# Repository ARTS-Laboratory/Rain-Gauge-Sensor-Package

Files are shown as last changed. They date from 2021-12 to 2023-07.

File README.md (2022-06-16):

# Rain-Gauge-Sensor-Package
Measuring the rain

<p align="center">
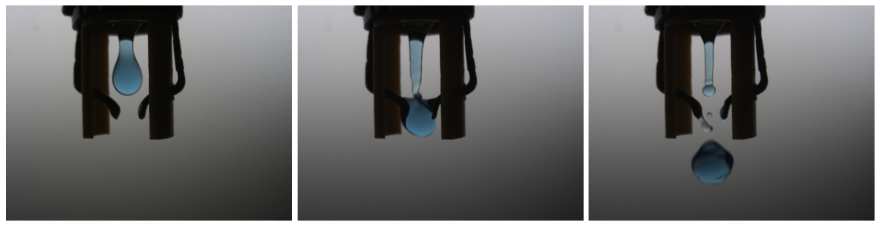
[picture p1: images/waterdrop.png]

</p>
<p align="center">
Figure 1: Water drops through the contacters.
</p>

<p align="center">
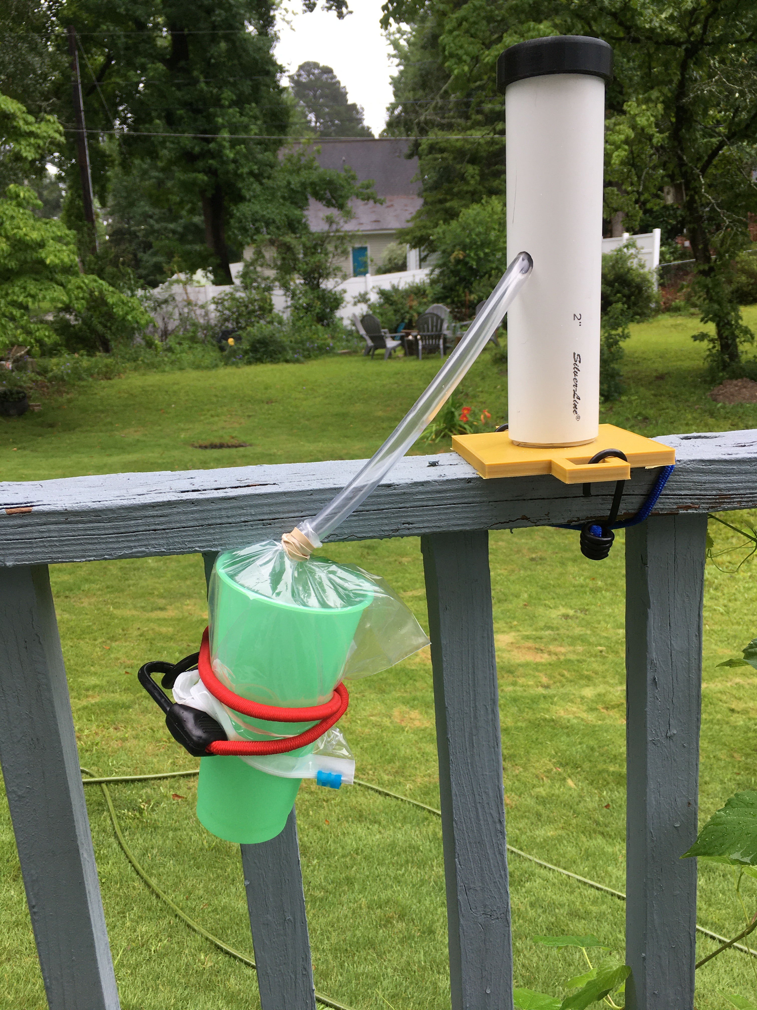
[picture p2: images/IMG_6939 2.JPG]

</p>
<p align="center">
Figure 2: Testing water drop measurments in (Saif 2021).
</p>

<p align="center">
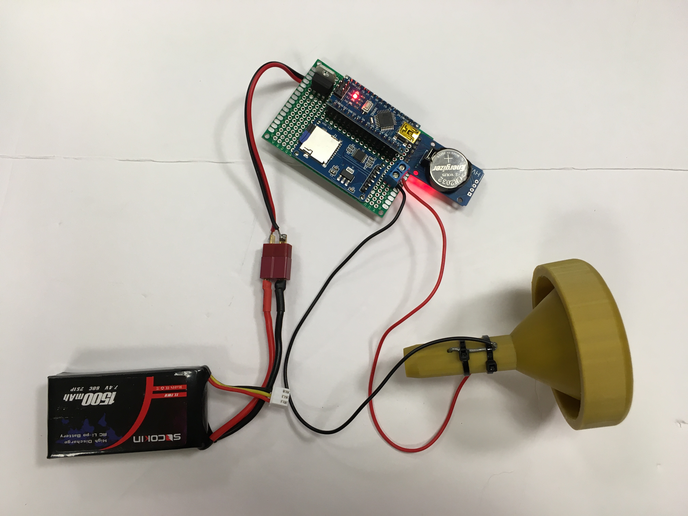
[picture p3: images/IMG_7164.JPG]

</p>
<p align="center">
Figure 3: Prototype hardware.
</p>

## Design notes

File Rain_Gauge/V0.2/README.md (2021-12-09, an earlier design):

# magDrone/Hydrologic Parameters/V0 Development/V 0.6/Raingauge
This is the drop counter verson of the raingauge for all previous versions see v0.5 folder (piezoelectric, resistivity, capacitance, and pressure)

##  How it works
- See powerpoint
- Raindrops are funneled together
- Individual drops are reformed using a Nozzle
- Individual drops fall from nozzle and are detected by electroids
- Drops continue into collection area and drain from the system

## As of 5/6/2021
- Drop formation size of 0.007675 in^3/drop
- Intake area of 4.43014 in^2
- Resolution of 0.001732 inches of water (per drop)

### What we have
- CAD files
  - Funnel
  - Nozzle/electrodes/drainage system
- Lab testing
- Data results

###  Next Steps
- integrate with PCB package
- Outdoor testing
- Get more data
- Find optimum nozzle parameters
- Determine drop parameters for nozzle
- CFD of drop formation

##### NOTE: Project being passed of from Richard Keith Matthews as of 5/6/2021. Email: Keithmatthews440@gmail.com

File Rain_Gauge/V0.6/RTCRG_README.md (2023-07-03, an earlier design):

## Update v0.6.2- June 2,2023
Current version is capable of turning on or off based on environmental humidity readings and an RTC interrupt. The RTC also logs the time it detects rainfall.

# Purpose of this project is to create an electronic rain gauge that can be deployed long term. It measures rainfall by counting individual rain drops as they make contact with two electrodes. The overall design is that of a funnel that guides rain through the electrodes so they can be counted individually, and saves this data, along with the time and humidity, to a microSD card.

BOM: Arduino Nano, BME280, 3.3v microSD card adapter, RTC module, 10uF capacitor, 3M ohm resistor, 5V and 3.3V linear regulators, 7.4V lipo battery

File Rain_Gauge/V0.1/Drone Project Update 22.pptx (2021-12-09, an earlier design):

## Rainfall sensor Update

Keith Matthews

## Rainfall sensor

- No moving parts
- High accuracy: drop counting
- Counts individual drops per area
- Converted to inches/hour
- Water drains out the bottom

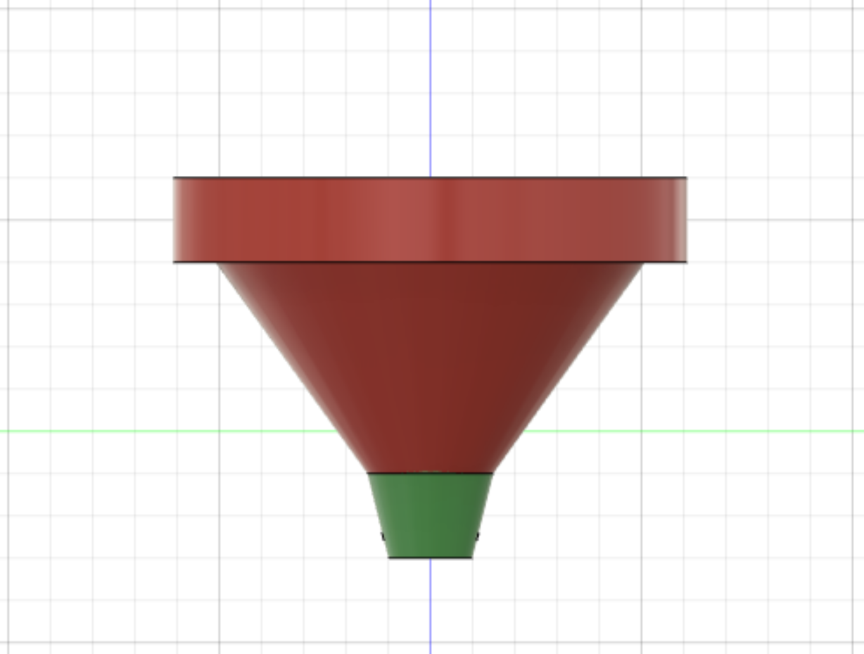
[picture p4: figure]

Funnel

Internal Nozzle

Electrodes

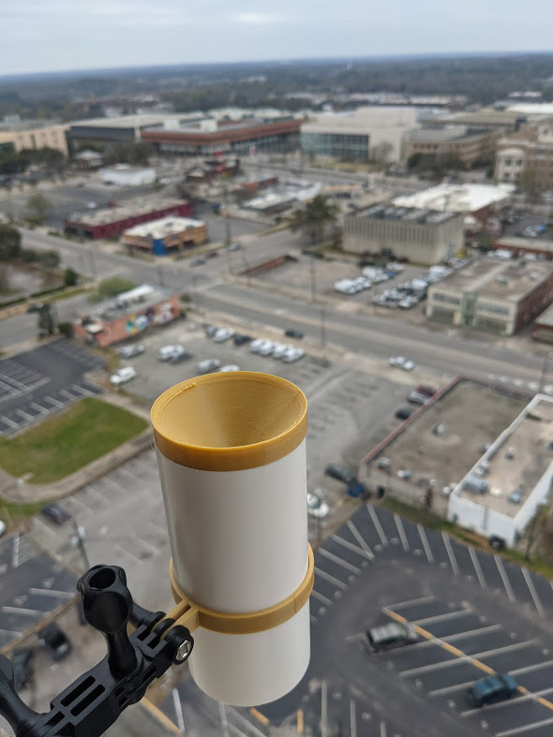
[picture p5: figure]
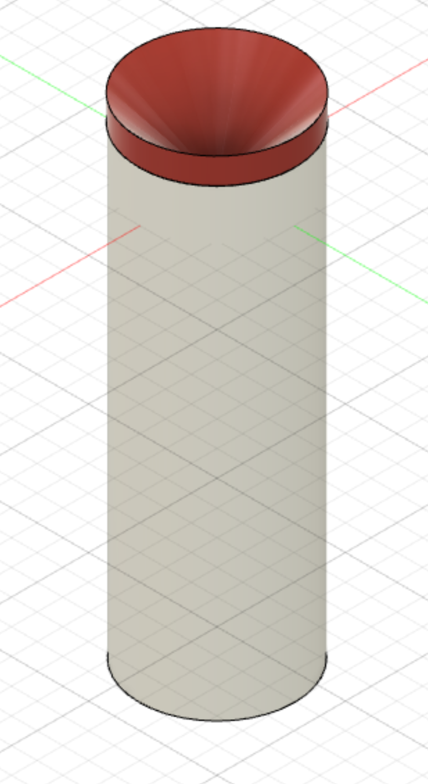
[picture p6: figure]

## Thoughts, Question, or Advise?

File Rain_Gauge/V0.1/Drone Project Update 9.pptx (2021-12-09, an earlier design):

## Water probe and Rainfall sensor Update

Keith Matthews

## Measuring Nitrates

- Chemical Test: Ring Test (iron(II) sulfate and sulfuric acid)
- In Situ with UV absorption?
  - Servo: to move the diffuser
  - Monochromator
  - Source (Sun?)
  - Detector (photosensor)
- Measurement range
- Detect other materials in the water?

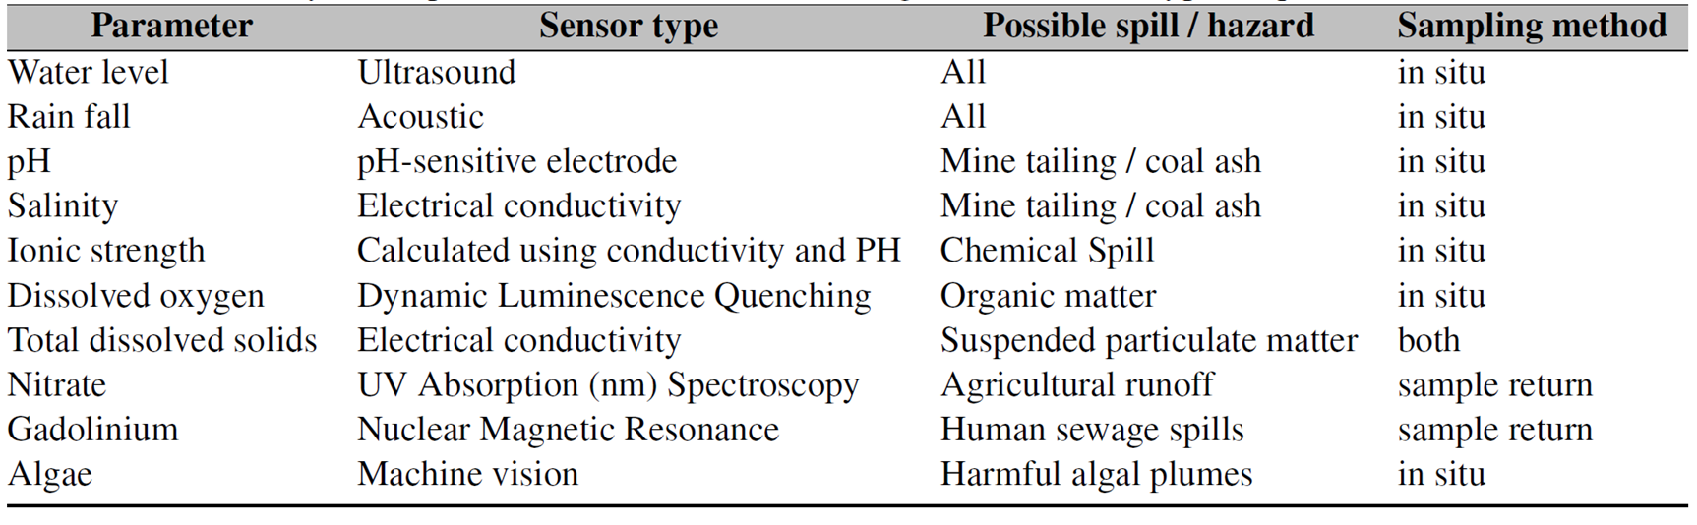
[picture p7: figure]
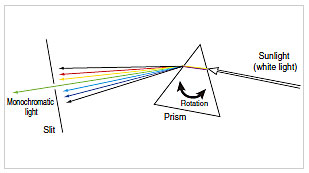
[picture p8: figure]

Monochromator

Angle determines the wavelength

## Nitrates

- Determination of Nitrate in Water Containing Dissolved Organic Carbon by Ultraviolet Spectroscopy
- 200-205 nm & 300 nm
- 2 wavelengths avoid organic intereference

## Dissolved oxygen

- Rapid and precise determination of dissolved oxygen by spectrophotometry: Evaluation of interference from color and turbidity
- 430nm
- Low organic interference

## Uv absorption

- Sample return
  - Easiest
- Fixed wavelengths
  - Nitrates only
- Spectrum
  - Moving parts
  - ∆θ=∆λ= accuracy
  - Slit size = precision

## Battery

- Samsung cylinder batteries?
  - Stackable
  - Flexible design
  - One charger for all
- LiPo
- Charging?
- Replacing

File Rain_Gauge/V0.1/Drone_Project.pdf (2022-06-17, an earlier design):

# WATER PROBE AND RAINFALL SENSOR UPDATE

Keith Matthews

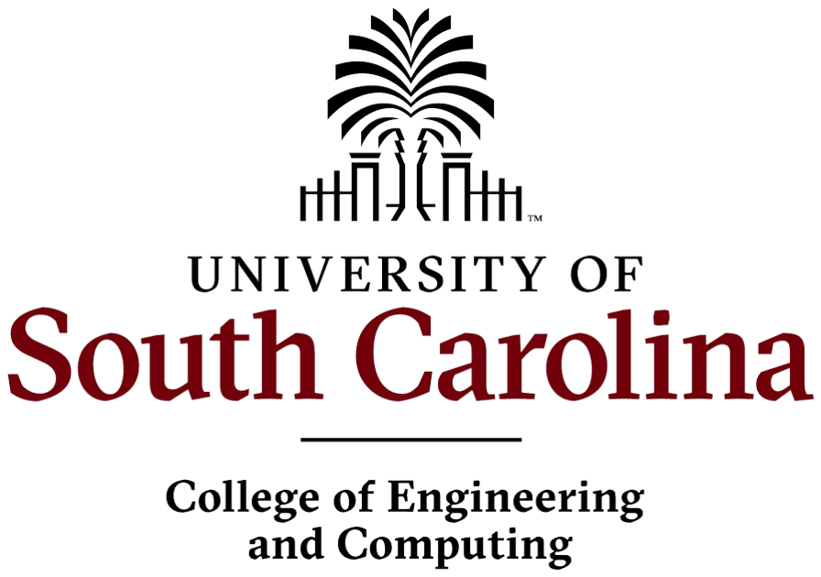
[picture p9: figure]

## RAINFALL SENSOR

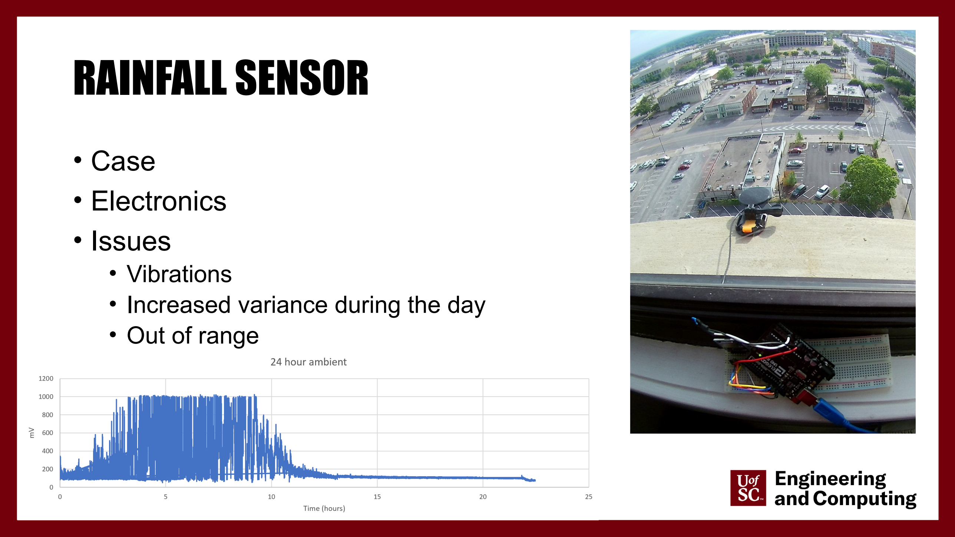
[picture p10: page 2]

- Case
- Electronics
- Issues
- Vibrations
- Increased variance during the day
- Out of range

## PIEZOELECTRIC RAINFALL SENSOR

- Conversion Factor
- Piezo: measurement mV
- Deflection- caused by Force
- Need “Velocity” – inches per hour
- Mathematical(ish)
- Voltage = Energy per electrical charge ~ Energy (constant amperes)
- Voltage ~ K.E. = (assume terminal velocity)
- Velocity
- Statistically
- Linear Regression:

## AUTO RIGHTING

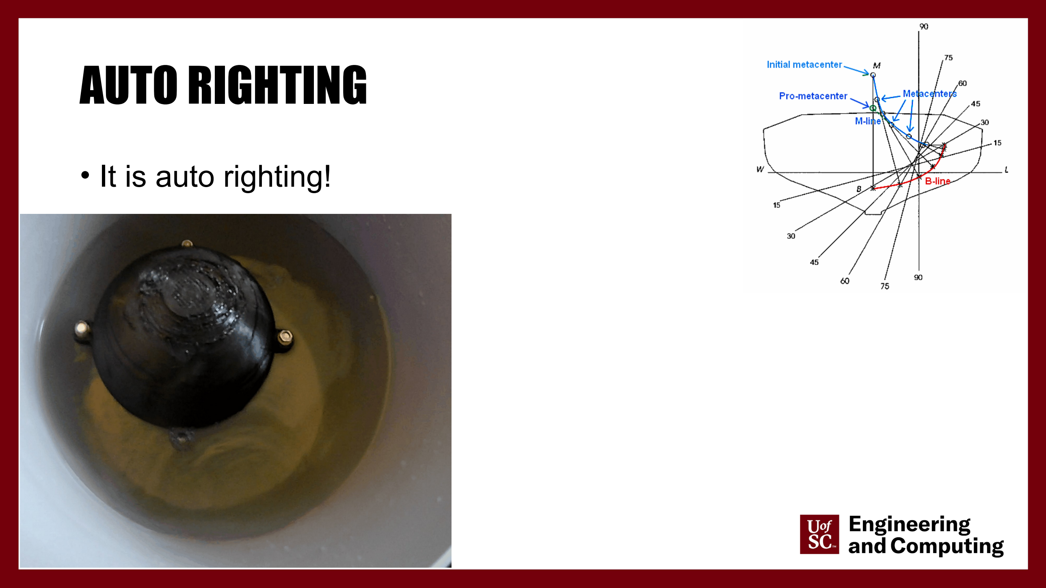
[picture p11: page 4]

- It is auto righting!

## WATERPROOF

- Mostly: only one leak
- Small imperfection in base print causing leak
- Higher quality prints take days
- Still not guaranteed
- Waterproof Electronics box

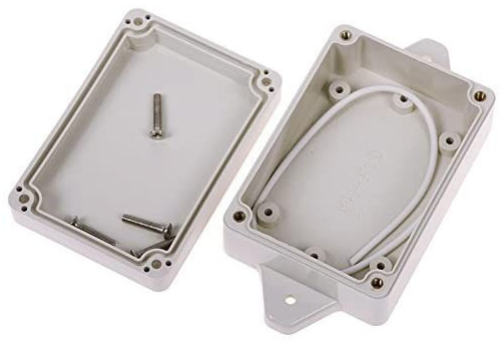
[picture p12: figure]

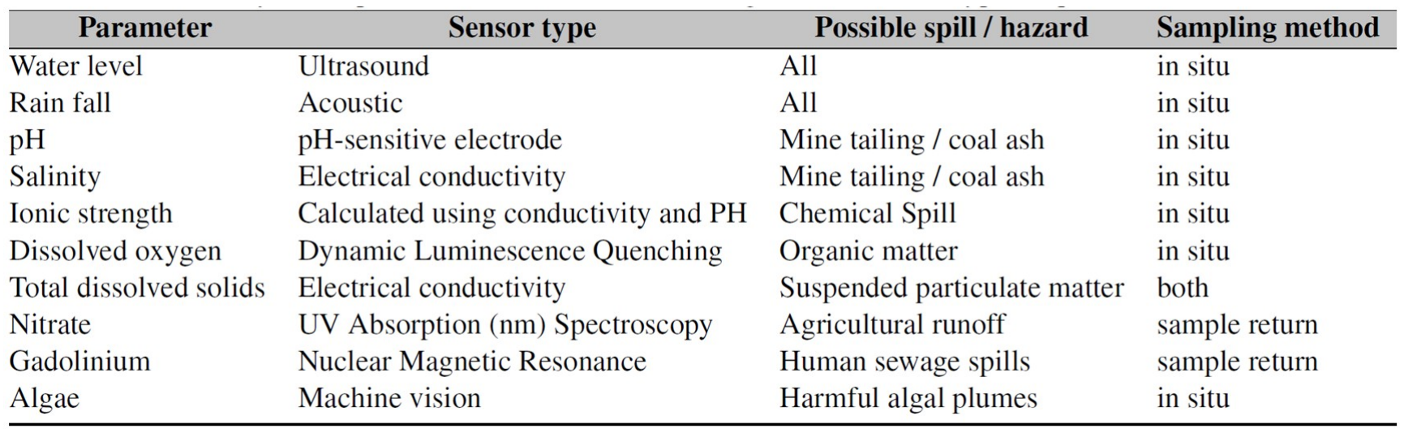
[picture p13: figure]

## MEASURING NITRATES

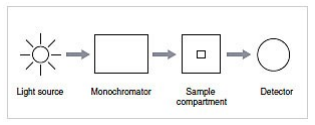
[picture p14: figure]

- Chemical Test: Ring Test (iron(II) sulfate and sulfuric acid)
- In Situ with UV absorption?
- Servo: to move the diffuser
- Monochromator
- Source (Sun?)
- Detector (photosensor)
- Measurement range
- Detect other materials in the water?

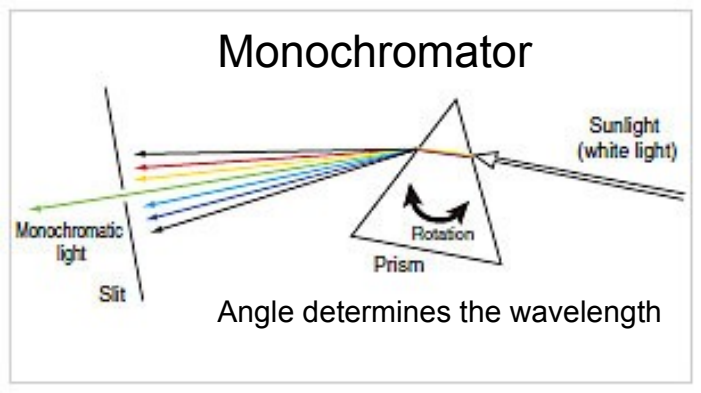
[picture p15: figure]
Angle determines the wavelength; Monochromator

## NEXT STEPS

- Rainfall
- Case V1
- Regression Equation
- Mounting System
- Water Probe
- Case V3
- Field testing
- Test Sensor System

## SOURCES

- https://pubs.rsc.org/en/content/articlelanding/2018/en/c8en0058 8e#!divAbstract (https://pubs.rsc.org/en/content/articlelanding/2018/en/c8en00588e#!divAbstract)
- http://www.pitt.edu/~asher/homepage/spec_pdf/UV%20Resona nce%20Raman%20Spectroscopic%20Detection%20of%20Nitra te.pdf (http://www.pitt.edu/~asher/homepage/spec_pdf/UV%20Resonance%20Raman%20Spectroscopic%20Detection%20of%20Nitrate.pdf)
- https://www.shimadzu.com/an/uv/support/fundamentals/monoch romators.html (https://www.shimadzu.com/an/uv/support/fundamentals/monochromators.html)

## DISSOLVED OXYGEN

## BATTERY

- Samsung cylinder batteries?
- Stackable
- Flexible design
- One charger for all
- LiPo
- Charging?
- Replacing

## TABLE OF PARAMETERS

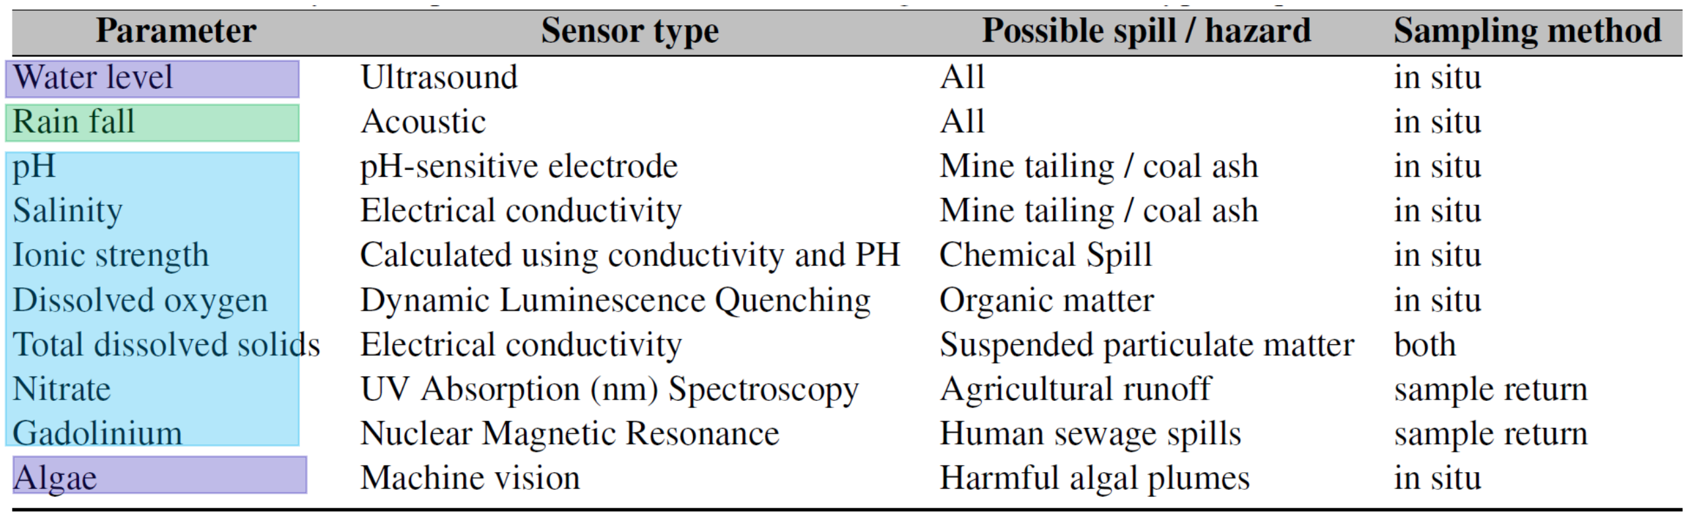
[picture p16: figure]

## PACKAGE CONDITIONS

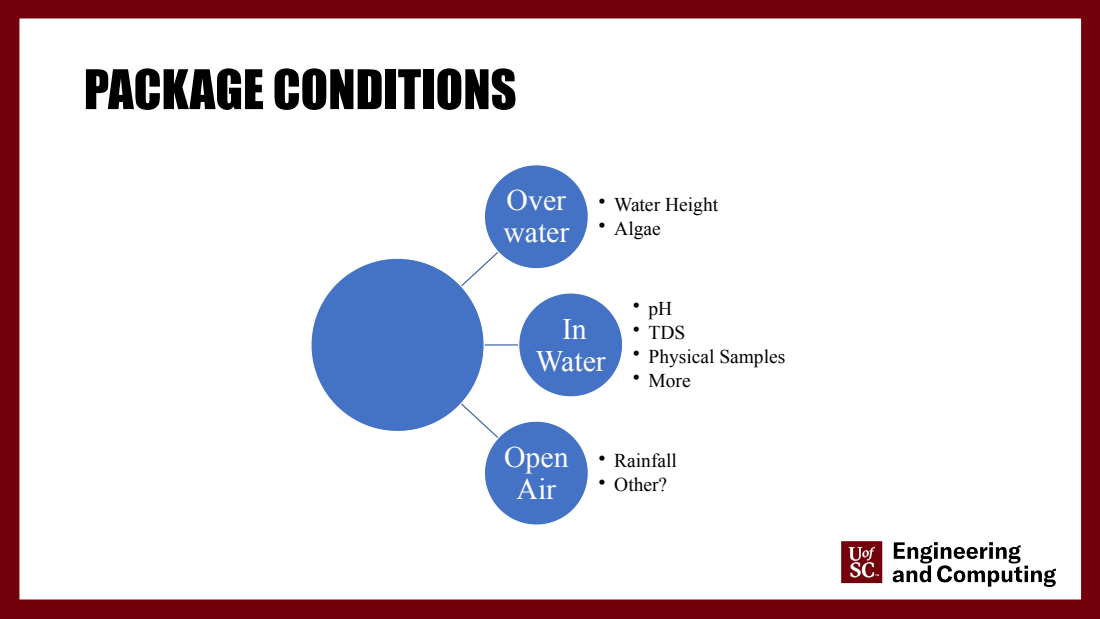
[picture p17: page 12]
Over water; • Water Height • Algae; In Water; • pH • TDS • Physical Samples • More; Open Air; • Rainfall • Other?

## 3 PACKAGES

- Above water package
- Currently the water height sensor package
- Add camera for algae machine vision detection capabilities
- In water package
- Under development
- Open air package
- Testing/development

## PROBE SWAP

- Easier
- Eliminates Docking

## MEASURING NITRATES

- Chemical Test: Ring Test (iron(II) sulfate and sulfuric acid)
- In Situ with UV absorption?
- Servo: to move the diffuser
- Monochromator
- Source (Sun?)
- Detector (photosensor)
- Measurement range
- Detect other materials in the water?

## NITRATES

- Determination of Nitrate in Water Containing Dissolved Organic Carbon by Ultraviolet Spectroscopy
- 200-205 nm & 300 nm
- 2 wavelengths avoid organic intereference

## DISSOLVED OXYGEN

- Rapid and precise
determination of dissolved oxygen by
spectrophotometry:
Evaluation of interference from color and turbidity
- 430nm
- Low organic interference

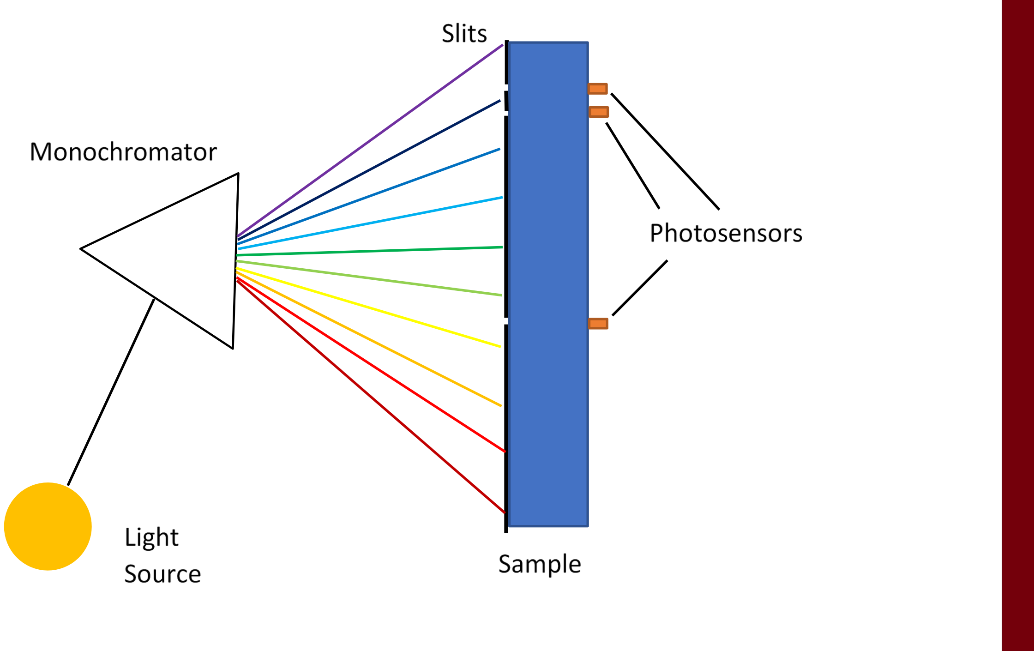
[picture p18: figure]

## UV ABSORPTION

- Sample return
- Easiest
- Fixed wavelengths
- Nitrates only
- Spectrum
- Moving parts
- accuracy
- Slit size precision

## BATTERY

- Samsung cylinder batteries?
- Stackable
- Flexible design
- One charger for all
- LiPo
- Charging?
- Replacing

## DATA

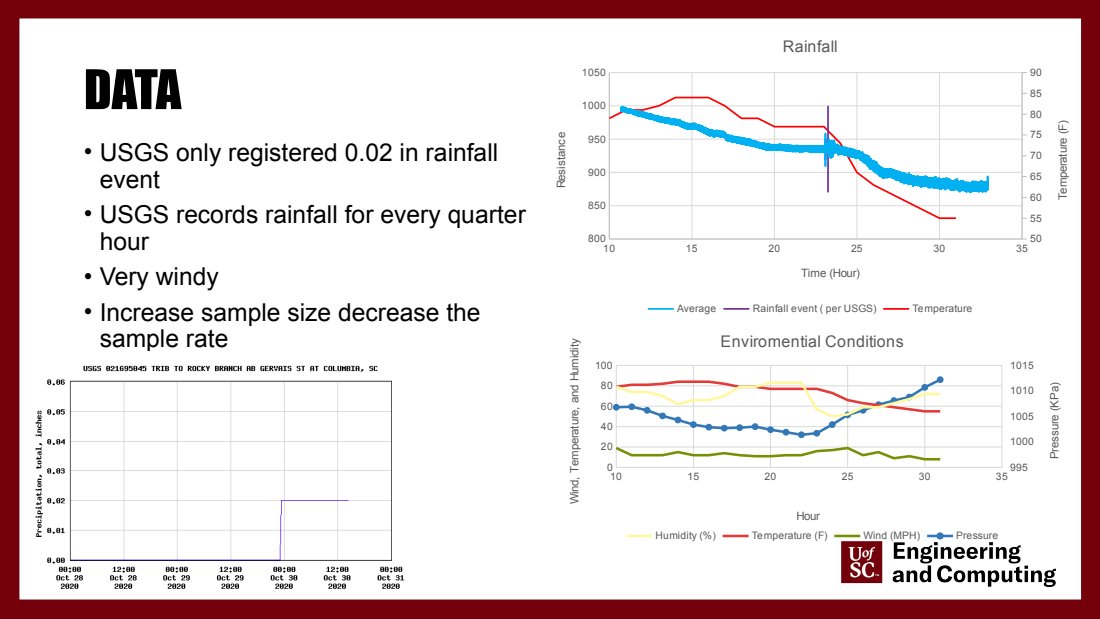
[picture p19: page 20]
Rainfall; Average; Rainfall event ( per USGS); Temperature; Time (Hour); Resistanc; erature (F); Enviromential Conditions; Humidity (%); Temperature (F); Wind (MPH); Pressure; Hour; Wind, T; erature, and; Humidity; Pressure (K

• USGS only registered 0.02 in rainfall
event
• USGS records rainfall for every quarter
hour
• Very windy
• Increase sample size decrease the
sample rate

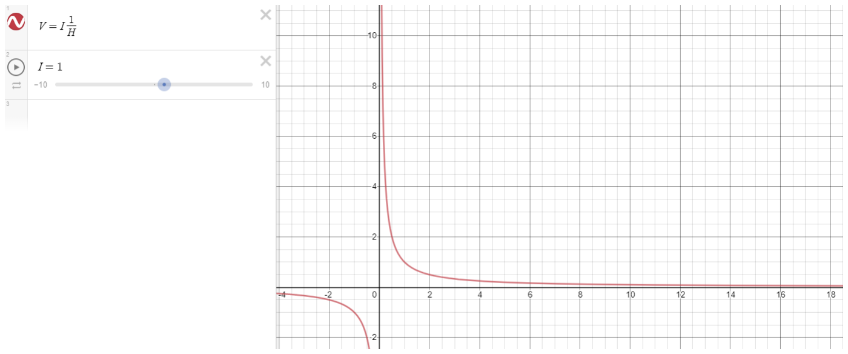
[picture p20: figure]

## REDESIGN TOP PIECE

- Deformation internal electrode holder
- Due to heat
- Make thicker and connect
- Reciprocal Function
- V=IR = I*(1/H)
- Flatten the curve
- Increase the current
- Angle the electrodes?
0 | 2 | 4 | 6 | 8 | 10 | 12

0

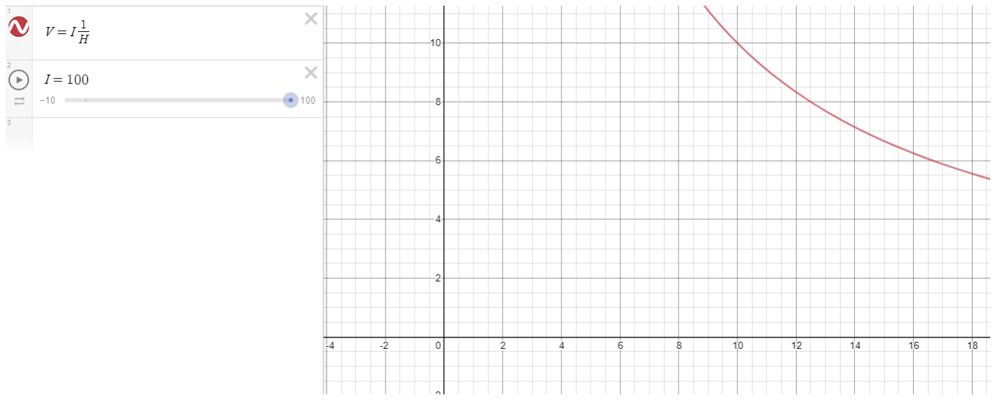
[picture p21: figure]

2

4

6

8

10

12

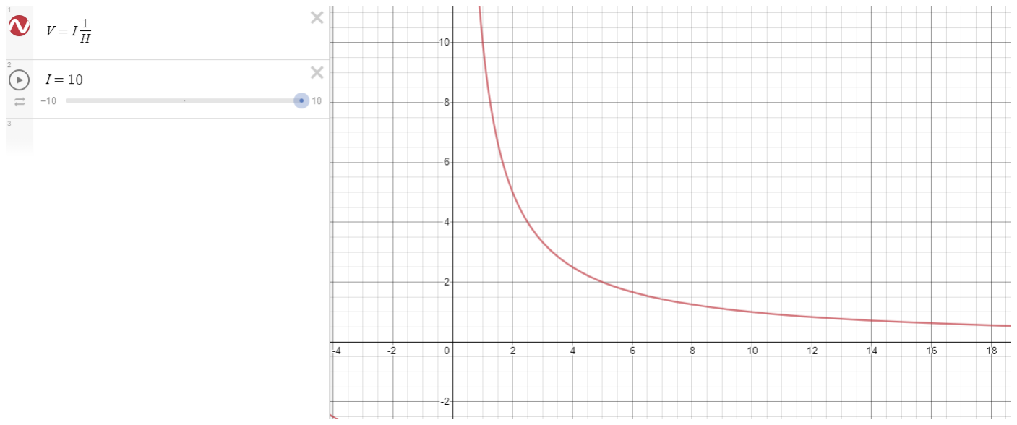
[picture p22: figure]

## NEW TOP

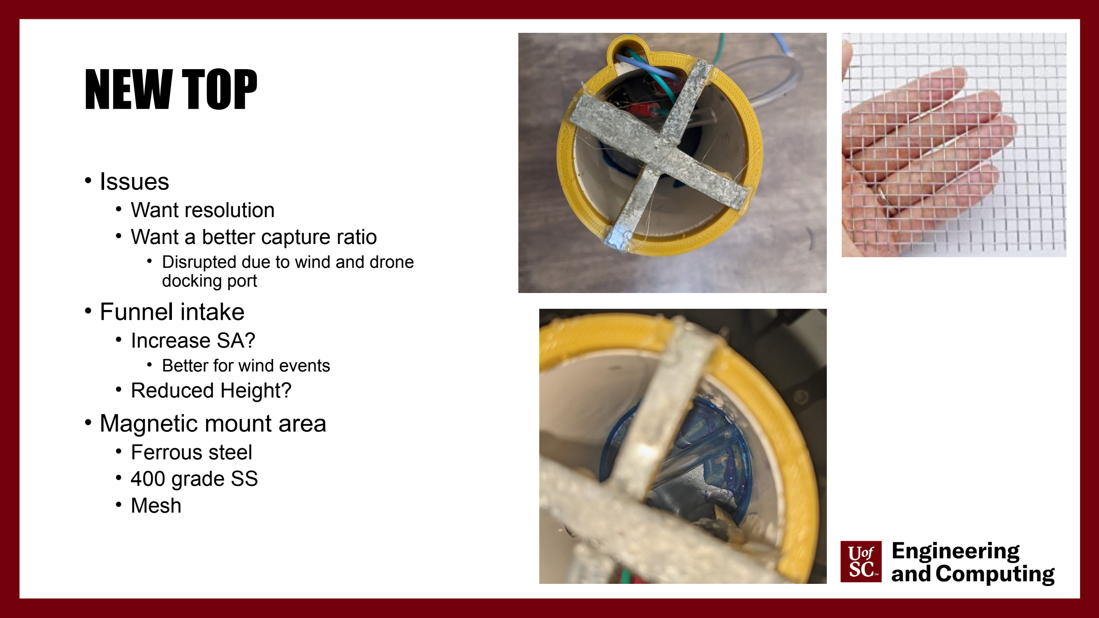
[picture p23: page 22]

- Issues
- Want resolution
- Want a better capture ratio
- Disrupted due to wind and drone docking port
- Funnel intake
- Increase SA?
- Better for wind events
- Reduced Height?
- Magnetic mount area
- Ferrous steel
- 400 grade SS
- Mesh

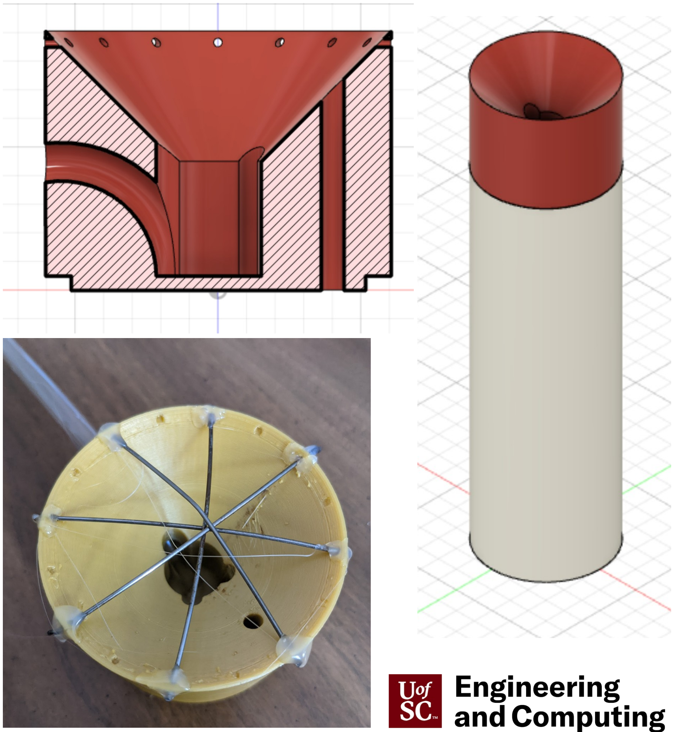
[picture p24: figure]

## NEW TOP

- Reduced overall height
(reduction of 40mm)
- Easier assembly
- Internal wiring
- More accurate data
(ratio of ~16:1)

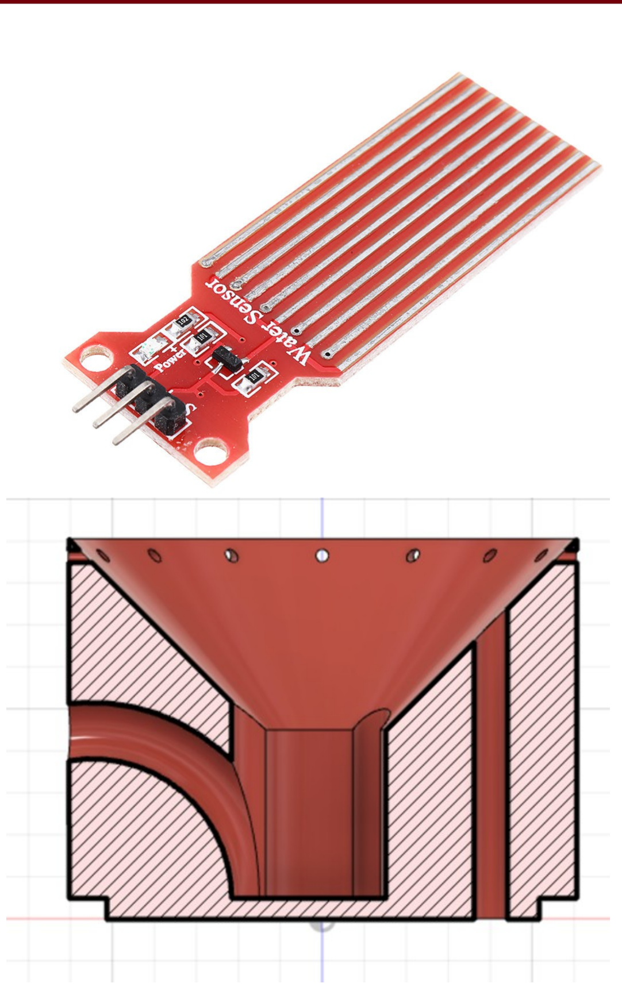
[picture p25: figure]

## CAPACITANCE

- Starting capacitance of 11.2768 pF (for rainfall of 0.01 in at a separation of 1mm)*
- Issue: Arduino can measure down to 100 nF*
- How to fix the issue
- Different circuit?
- Increase intake ratio
- Change to PCB sensor (coat with a material)

## RAINFALL SENSOR

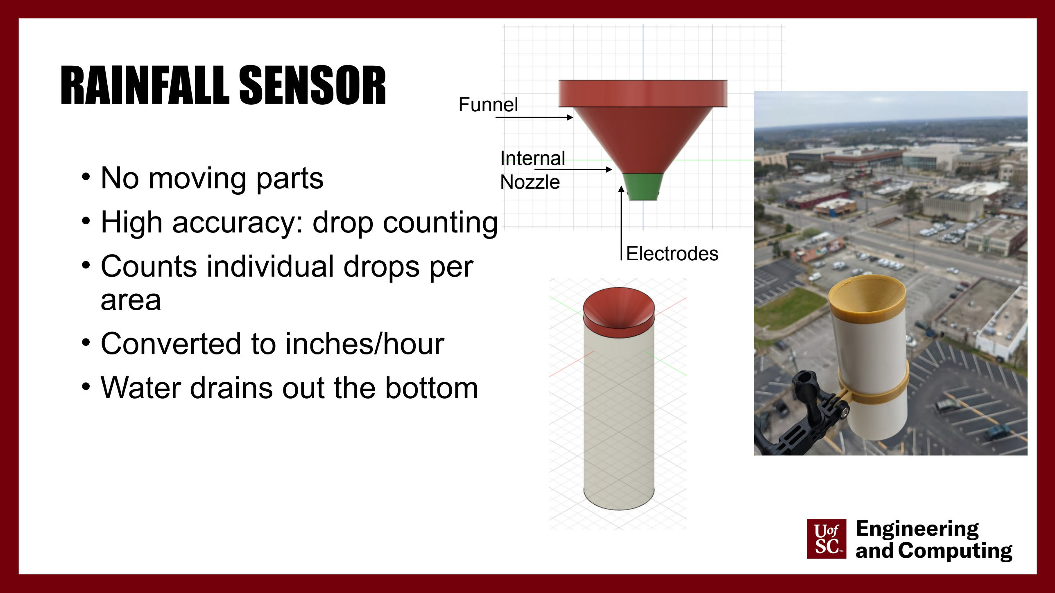
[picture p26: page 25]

- No moving parts
- High accuracy: drop counting
- Counts individual drops per area
- Converted to inches/hour
- Water drains out the bottom

Funnel

Internal
Nozzle

Electrodes

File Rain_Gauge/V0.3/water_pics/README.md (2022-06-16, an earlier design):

# Rain gauge water pictures

<p align="center">
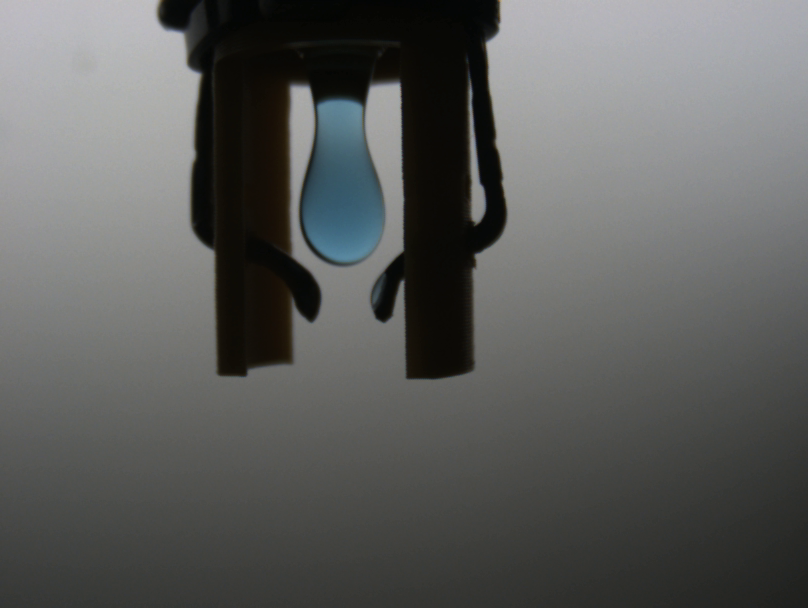
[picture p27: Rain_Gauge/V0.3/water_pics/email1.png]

</p>

<p align="center">

</p>

<p align="center">

</p>

<p align="center">

</p>

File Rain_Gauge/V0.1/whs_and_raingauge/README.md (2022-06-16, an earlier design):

# Rain gauge

<p align="center">

</p>

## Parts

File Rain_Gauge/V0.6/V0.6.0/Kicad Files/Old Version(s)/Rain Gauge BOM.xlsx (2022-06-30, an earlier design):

version | source | date | tool | number | name | tstamps | title | company | rev | date2 | source3 | number4 | value | ref | value5 | footprint | datasheet | lib | part | description | name6 | value7 | names | tstamps8 | tstamps9 | lib10 | part11 | description12 | docs | fp | field | name13 | num | name14 | type | logical | uri | code | name15 | ref16 | pin | pinfunction | pintype
E | C:\Users\cheap\OneDrive\Documents\USC Arduino Lab Projects\Rain Gauge\Rain Gauge\Rain Gauge.kicad_sch | 6/30/2022 3:24:30 PM | Eeschema (6.0.5) | 1 | / | / |  |  |  |  | Rain Gauge.kicad_sch | 1
E | C:\Users\cheap\OneDrive\Documents\USC Arduino Lab Projects\Rain Gauge\Rain Gauge\Rain Gauge.kicad_sch | 6/30/2022 3:24:30 PM | Eeschema (6.0.5) | 1 | / | / |  |  |  |  | Rain Gauge.kicad_sch | 2
E | C:\Users\cheap\OneDrive\Documents\USC Arduino Lab Projects\Rain Gauge\Rain Gauge\Rain Gauge.kicad_sch | 6/30/2022 3:24:30 PM | Eeschema (6.0.5) | 1 | / | / |  |  |  |  | Rain Gauge.kicad_sch | 3
E | C:\Users\cheap\OneDrive\Documents\USC Arduino Lab Projects\Rain Gauge\Rain Gauge\Rain Gauge.kicad_sch | 6/30/2022 3:24:30 PM | Eeschema (6.0.5) | 1 | / | / |  |  |  |  | Rain Gauge.kicad_sch | 4
E | C:\Users\cheap\OneDrive\Documents\USC Arduino Lab Projects\Rain Gauge\Rain Gauge\Rain Gauge.kicad_sch | 6/30/2022 3:24:30 PM | Eeschema (6.0.5) | 1 | / | / |  |  |  |  | Rain Gauge.kicad_sch | 5
E | C:\Users\cheap\OneDrive\Documents\USC Arduino Lab Projects\Rain Gauge\Rain Gauge\Rain Gauge.kicad_sch | 6/30/2022 3:24:30 PM | Eeschema (6.0.5) | 1 | / | / |  |  |  |  | Rain Gauge.kicad_sch | 6
E | C:\Users\cheap\OneDrive\Documents\USC Arduino Lab Projects\Rain Gauge\Rain Gauge\Rain Gauge.kicad_sch | 6/30/2022 3:24:30 PM | Eeschema (6.0.5) | 1 | / | / |  |  |  |  | Rain Gauge.kicad_sch | 7
E | C:\Users\cheap\OneDrive\Documents\USC Arduino Lab Projects\Rain Gauge\Rain Gauge\Rain Gauge.kicad_sch | 6/30/2022 3:24:30 PM | Eeschema (6.0.5) | 1 | / | / |  |  |  |  | Rain Gauge.kicad_sch | 8
E | C:\Users\cheap\OneDrive\Documents\USC Arduino Lab Projects\Rain Gauge\Rain Gauge\Rain Gauge.kicad_sch | 6/30/2022 3:24:30 PM | Eeschema (6.0.5) | 1 | / | / |  |  |  |  | Rain Gauge.kicad_sch | 9
E |  |  |  |  |  |  |  |  |  |  |  |  |  | A1 | Arduino_Nano_Every
E |  |  |  |  |  |  |  |  |  |  |  |  |  | A1 |  | Module:Arduino_Nano
E |  |  |  |  |  |  |  |  |  |  |  |  |  | A1 |  |  | https://content.arduino.cc/assets/NANOEveryV3.0_sch.pdf
E |  |  |  |  |  |  |  |  |  |  |  |  |  | A1 |  |  |  | MCU_Module | Arduino_Nano_Every | Arduino Nano Every
E |  |  |  |  |  |  |  |  |  |  |  |  |  | A1 |  |  |  |  |  |  | Sheetname
E |  |  |  |  |  |  |  |  |  |  |  |  |  | A1 |  |  |  |  |  |  | Sheetfile | Rain Gauge.kicad_sch
E |  |  |  |  |  |  |  |  |  |  |  |  |  | A1 |  |  |  |  |  |  |  |  | / | /
E |  |  |  |  |  |  |  |  |  |  |  |  |  | A1 |  |  |  |  |  |  |  |  |  |  | a3730633-183c-479b-949b-19a5c7cade81
E |  |  |  |  |  |  |  |  |  |  |  |  |  | Q1 | PN2222A
E |  |  |  |  |  |  |  |  |  |  |  |  |  | Q1 |  | Package_TO_SOT_THT:TO-92_Inline
E |  |  |  |  |  |  |  |  |  |  |  |  |  | Q1 |  |  | https://www.onsemi.com/pub/Collateral/PN2222-D.PDF
E |  |  |  |  |  |  |  |  |  |  |  |  |  | Q1 |  |  |  | Transistor_BJT | PN2222A | 1A Ic, 40V Vce, NPN Transistor, General Purpose Transistor, TO-92
E |  |  |  |  |  |  |  |  |  |  |  |  |  | Q1 |  |  |  |  |  |  | Sheetname
E |  |  |  |  |  |  |  |  |  |  |  |  |  | Q1 |  |  |  |  |  |  | Sheetfile | Rain Gauge.kicad_sch
E |  |  |  |  |  |  |  |  |  |  |  |  |  | Q1 |  |  |  |  |  |  |  |  | / | /
E |  |  |  |  |  |  |  |  |  |  |  |  |  | Q1 |  |  |  |  |  |  |  |  |  |  | 06652ac3-f885-4b8b-aec8-8d464a589341
E |  |  |  |  |  |  |  |  |  |  |  |  |  | R1 | 220
E |  |  |  |  |  |  |  |  |  |  |  |  |  | R1 |  | Resistor_THT:R_Axial_DIN0207_L6.3mm_D2.5mm_P15.24mm_Horizontal
E |  |  |  |  |  |  |  |  |  |  |  |  |  | R1 |  |  |  | Device | R | Resistor
E |  |  |  |  |  |  |  |  |  |  |  |  |  | R1 |  |  |  |  |  |  | Sheetname
E |  |  |  |  |  |  |  |  |  |  |  |  |  | R1 |  |  |  |  |  |  | Sheetfile | Rain Gauge.kicad_sch
E |  |  |  |  |  |  |  |  |  |  |  |  |  | R1 |  |  |  |  |  |  |  |  | / | /
E |  |  |  |  |  |  |  |  |  |  |  |  |  | R1 |  |  |  |  |  |  |  |  |  |  | f49a5aaf-69c3-44ed-a95e-0fbcec4985c0
E |  |  |  |  |  |  |  |  |  |  |  |  |  | R2 | 3M
E |  |  |  |  |  |  |  |  |  |  |  |  |  | R2 |  | Resistor_THT:R_Axial_DIN0207_L6.3mm_D2.5mm_P15.24mm_Horizontal
E |  |  |  |  |  |  |  |  |  |  |  |  |  | R2 |  |  |  | Device | R | Resistor
E |  |  |  |  |  |  |  |  |  |  |  |  |  | R2 |  |  |  |  |  |  | Sheetname
E |  |  |  |  |  |  |  |  |  |  |  |  |  | R2 |  |  |  |  |  |  | Sheetfile | Rain Gauge.kicad_sch
E |  |  |  |  |  |  |  |  |  |  |  |  |  | R2 |  |  |  |  |  |  |  |  | / | /
E |  |  |  |  |  |  |  |  |  |  |  |  |  | R2 |  |  |  |  |  |  |  |  |  |  | 8ccdc973-468d-4277-bfcb-4269ffbd10ca
E |  |  |  |  |  |  |  |  |  |  |  |  |  | U1 | SD_Adapter
E |  |  |  |  |  |  |  |  |  |  |  |  |  | U1 |  | Rain Gauge:3.3v SD Adapter
E |  |  |  |  |  |  |  |  |  |  |  |  |  | U1 |  |  |  | Rain Gauge lib | SD_Adapter
E |  |  |  |  |  |  |  |  |  |  |  |  |  | U1 |  |  |  |  |  |  | Sheetname
E |  |  |  |  |  |  |  |  |  |  |  |  |  | U1 |  |  |  |  |  |  | Sheetfile | Rain Gauge.kicad_sch
E |  |  |  |  |  |  |  |  |  |  |  |  |  | U1 |  |  |  |  |  |  |  |  | / | /
E |  |  |  |  |  |  |  |  |  |  |  |  |  | U1 |  |  |  |  |  |  |  |  |  |  | c1e2cf6c-7d20-47da-938a-e7ca17dc9614
E |  |  |  |  |  |  |  |  |  |  |  |  |  | U2 | BME280
E |  |  |  |  |  |  |  |  |  |  |  |  |  | U2 |  | Rain Gauge:BME280
E |  |  |  |  |  |  |  |  |  |  |  |  |  | U2 |  |  |  | Rain Gauge lib | BME280
E |  |  |  |  |  |  |  |  |  |  |  |  |  | U2 |  |  |  |  |  |  | Sheetname
E |  |  |  |  |  |  |  |  |  |  |  |  |  | U2 |  |  |  |  |  |  | Sheetfile | Rain Gauge.kicad_sch
E |  |  |  |  |  |  |  |  |  |  |  |  |  | U2 |  |  |  |  |  |  |  |  | / | /
E |  |  |  |  |  |  |  |  |  |  |  |  |  | U2 |  |  |  |  |  |  |  |  |  |  | e57cb767-ce1c-4006-bfb7-99a1e75ff09a
E |  |  |  |  |  |  |  |  |  |  |  |  |  | U3 | Lipo
E |  |  |  |  |  |  |  |  |  |  |  |  |  | U3 |  | Rain Gauge:Lipo
E |  |  |  |  |  |  |  |  |  |  |  |  |  | U3 |  |  |  | Rain Gauge lib | Lipo
E |  |  |  |  |  |  |  |  |  |  |  |  |  | U3 |  |  |  |  |  |  | Sheetname
E |  |  |  |  |  |  |  |  |  |  |  |  |  | U3 |  |  |  |  |  |  | Sheetfile | Rain Gauge.kicad_sch
E |  |  |  |  |  |  |  |  |  |  |  |  |  | U3 |  |  |  |  |  |  |  |  | / | /
E |  |  |  |  |  |  |  |  |  |  |  |  |  | U3 |  |  |  |  |  |  |  |  |  |  | 3c9bff11-4ddf-44c8-8daa-077df29b021a
E |  |  |  |  |  |  |  |  |  |  |  |  |  | U4 | Electrode
E |  |  |  |  |  |  |  |  |  |  |  |  |  | U4 |  | Rain Gauge:Electrode
E |  |  |  |  |  |  |  |  |  |  |  |  |  | U4 |  |  |  | Rain Gauge lib | Electrode
E |  |  |  |  |  |  |  |  |  |  |  |  |  | U4 |  |  |  |  |  |  | Sheetname
E |  |  |  |  |  |  |  |  |  |  |  |  |  | U4 |  |  |  |  |  |  | Sheetfile | Rain Gauge.kicad_sch
E |  |  |  |  |  |  |  |  |  |  |  |  |  | U4 |  |  |  |  |  |  |  |  | / | /
E |  |  |  |  |  |  |  |  |  |  |  |  |  | U4 |  |  |  |  |  |  |  |  |  |  | 3104f798-4ae3-457e-bd68-fcf9303288a0
E |  |  |  |  |  |  |  |  |  |  |  |  |  | U5 | Electrode
E |  |  |  |  |  |  |  |  |  |  |  |  |  | U5 |  | Rain Gauge:Electrode
E |  |  |  |  |  |  |  |  |  |  |  |  |  | U5 |  |  |  | Rain Gauge lib | Electrode
E |  |  |  |  |  |  |  |  |  |  |  |  |  | U5 |  |  |  |  |  |  | Sheetname
E |  |  |  |  |  |  |  |  |  |  |  |  |  | U5 |  |  |  |  |  |  | Sheetfile | Rain Gauge.kicad_sch
E |  |  |  |  |  |  |  |  |  |  |  |  |  | U5 |  |  |  |  |  |  |  |  | / | /
E |  |  |  |  |  |  |  |  |  |  |  |  |  | U5 |  |  |  |  |  |  |  |  |  |  | 57f75301-f686-4ddc-8d22-235bfd86b326
E |  |  |  |  |  |  |  |  |  |  |  |  |  |  |  |  |  |  |  |  |  |  |  |  |  | Device | R | Resistor | ~ | R_* | R | Reference
E |  |  |  |  |  |  |  |  |  |  |  |  |  |  |  |  |  |  |  |  |  |  |  |  |  | Device | R | Resistor | ~ | R_* | R | Value
E |  |  |  |  |  |  |  |  |  |  |  |  |  |  |  |  |  |  |  |  |  |  |  |  |  | Device | R | Resistor | ~ | R_* | ~ | Datasheet
E |  |  |  |  |  |  |  |  |  |  |  |  |  |  |  |  |  |  |  |  |  |  |  |  |  | Device | R | Resistor | ~ | R_* |  |  | 1 |  | passive
E |  |  |  |  |  |  |  |  |  |  |  |  |  |  |  |  |  |  |  |  |  |  |  |  |  | Device | R | Resistor | ~ | R_* |  |  | 2 |  | passive
E |  |  |  |  |  |  |  |  |  |  |  |  |  |  |  |  |  |  |  |  |  |  |  |  |  | MCU_Module | Arduino_Nano_Every | Arduino Nano Every | https://content.arduino.cc/assets/NANOEveryV3.0_sch.pdf | Arduino*Nano* | A | Reference
E |  |  |  |  |  |  |  |  |  |  |  |  |  |  |  |  |  |  |  |  |  |  |  |  |  | MCU_Module | Arduino_Nano_Every | Arduino Nano Every | https://content.arduino.cc/assets/NANOEveryV3.0_sch.pdf | Arduino*Nano* | Arduino_Nano_Every | Value
E |  |  |  |  |  |  |  |  |  |  |  |  |  |  |  |  |  |  |  |  |  |  |  |  |  | MCU_Module | Arduino_Nano_Every | Arduino Nano Every | https://content.arduino.cc/assets/NANOEveryV3.0_sch.pdf | Arduino*Nano* | Module:Arduino_Nano | Footprint
E |  |  |  |  |  |  |  |  |  |  |  |  |  |  |  |  |  |  |  |  |  |  |  |  |  | MCU_Module | Arduino_Nano_Every | Arduino Nano Every | https://content.arduino.cc/assets/NANOEveryV3.0_sch.pdf | Arduino*Nano* | https://content.arduino.cc/assets/NANOEveryV3.0_sch.pdf | Datasheet
E |  |  |  |  |  |  |  |  |  |  |  |  |  |  |  |  |  |  |  |  |  |  |  |  |  | MCU_Module | Arduino_Nano_Every | Arduino Nano Every | https://content.arduino.cc/assets/NANOEveryV3.0_sch.pdf | Arduino*Nano* |  |  | 1 | TX1 | bidirectional
E |  |  |  |  |  |  |  |  |  |  |  |  |  |  |  |  |  |  |  |  |  |  |  |  |  | MCU_Module | Arduino_Nano_Every | Arduino Nano Every | https://content.arduino.cc/assets/NANOEveryV3.0_sch.pdf | Arduino*Nano* |  |  | 2 | RX1 | bidirectional
E |  |  |  |  |  |  |  |  |  |  |  |  |  |  |  |  |  |  |  |  |  |  |  |  |  | MCU_Module | Arduino_Nano_Every | Arduino Nano Every | https://content.arduino.cc/assets/NANOEveryV3.0_sch.pdf | Arduino*Nano* |  |  | 3 | ~{RESET} | input
E |  |  |  |  |  |  |  |  |  |  |  |  |  |  |  |  |  |  |  |  |  |  |  |  |  | MCU_Module | Arduino_Nano_Every | Arduino Nano Every | https://content.arduino.cc/assets/NANOEveryV3.0_sch.pdf | Arduino*Nano* |  |  | 4 | GND | power_in
E |  |  |  |  |  |  |  |  |  |  |  |  |  |  |  |  |  |  |  |  |  |  |  |  |  | MCU_Module | Arduino_Nano_Every | Arduino Nano Every | https://content.arduino.cc/assets/NANOEveryV3.0_sch.pdf | Arduino*Nano* |  |  | 5 | D2 | bidirectional
E |  |  |  |  |  |  |  |  |  |  |  |  |  |  |  |  |  |  |  |  |  |  |  |  |  | MCU_Module | Arduino_Nano_Every | Arduino Nano Every | https://content.arduino.cc/assets/NANOEveryV3.0_sch.pdf | Arduino*Nano* |  |  | 6 | D3 | bidirectional
E |  |  |  |  |  |  |  |  |  |  |  |  |  |  |  |  |  |  |  |  |  |  |  |  |  | MCU_Module | Arduino_Nano_Every | Arduino Nano Every | https://content.arduino.cc/assets/NANOEveryV3.0_sch.pdf | Arduino*Nano* |  |  | 7 | D4 | bidirectional
E |  |  |  |  |  |  |  |  |  |  |  |  |  |  |  |  |  |  |  |  |  |  |  |  |  | MCU_Module | Arduino_Nano_Every | Arduino Nano Every | https://content.arduino.cc/assets/NANOEveryV3.0_sch.pdf | Arduino*Nano* |  |  | 8 | D5 | bidirectional
E |  |  |  |  |  |  |  |  |  |  |  |  |  |  |  |  |  |  |  |  |  |  |  |  |  | MCU_Module | Arduino_Nano_Every | Arduino Nano Every | https://content.arduino.cc/assets/NANOEveryV3.0_sch.pdf | Arduino*Nano* |  |  | 9 | D6 | bidirectional
E |  |  |  |  |  |  |  |  |  |  |  |  |  |  |  |  |  |  |  |  |  |  |  |  |  | MCU_Module | Arduino_Nano_Every | Arduino Nano Every | https://content.arduino.cc/assets/NANOEveryV3.0_sch.pdf | Arduino*Nano* |  |  | 10 | D7 | bidirectional
E |  |  |  |  |  |  |  |  |  |  |  |  |  |  |  |  |  |  |  |  |  |  |  |  |  | MCU_Module | Arduino_Nano_Every | Arduino Nano Every | https://content.arduino.cc/assets/NANOEveryV3.0_sch.pdf | Arduino*Nano* |  |  | 11 | D8 | bidirectional
E |  |  |  |  |  |  |  |  |  |  |  |  |  |  |  |  |  |  |  |  |  |  |  |  |  | MCU_Module | Arduino_Nano_Every | Arduino Nano Every | https://content.arduino.cc/assets/NANOEveryV3.0_sch.pdf | Arduino*Nano* |  |  | 12 | D9 | bidirectional
E |  |  |  |  |  |  |  |  |  |  |  |  |  |  |  |  |  |  |  |  |  |  |  |  |  | MCU_Module | Arduino_Nano_Every | Arduino Nano Every | https://content.arduino.cc/assets/NANOEveryV3.0_sch.pdf | Arduino*Nano* |  |  | 13 | D10 | bidirectional
E |  |  |  |  |  |  |  |  |  |  |  |  |  |  |  |  |  |  |  |  |  |  |  |  |  | MCU_Module | Arduino_Nano_Every | Arduino Nano Every | https://content.arduino.cc/assets/NANOEveryV3.0_sch.pdf | Arduino*Nano* |  |  | 14 | MOSI | bidirectional
E |  |  |  |  |  |  |  |  |  |  |  |  |  |  |  |  |  |  |  |  |  |  |  |  |  | MCU_Module | Arduino_Nano_Every | Arduino Nano Every | https://content.arduino.cc/assets/NANOEveryV3.0_sch.pdf | Arduino*Nano* |  |  | 15 | MISO | bidirectional
E |  |  |  |  |  |  |  |  |  |  |  |  |  |  |  |  |  |  |  |  |  |  |  |  |  | MCU_Module | Arduino_Nano_Every | Arduino Nano Every | https://content.arduino.cc/assets/NANOEveryV3.0_sch.pdf | Arduino*Nano* |  |  | 16 | SCK | bidirectional
E |  |  |  |  |  |  |  |  |  |  |  |  |  |  |  |  |  |  |  |  |  |  |  |  |  | MCU_Module | Arduino_Nano_Every | Arduino Nano Every | https://content.arduino.cc/assets/NANOEveryV3.0_sch.pdf | Arduino*Nano* |  |  | 17 | 3V3 | power_out
E |  |  |  |  |  |  |  |  |  |  |  |  |  |  |  |  |  |  |  |  |  |  |  |  |  | MCU_Module | Arduino_Nano_Every | Arduino Nano Every | https://content.arduino.cc/assets/NANOEveryV3.0_sch.pdf | Arduino*Nano* |  |  | 18 | AREF | input
E |  |  |  |  |  |  |  |  |  |  |  |  |  |  |  |  |  |  |  |  |  |  |  |  |  | MCU_Module | Arduino_Nano_Every | Arduino Nano Every | https://content.arduino.cc/assets/NANOEveryV3.0_sch.pdf | Arduino*Nano* |  |  | 19 | A0 | bidirectional
E |  |  |  |  |  |  |  |  |  |  |  |  |  |  |  |  |  |  |  |  |  |  |  |  |  | MCU_Module | Arduino_Nano_Every | Arduino Nano Every | https://content.arduino.cc/assets/NANOEveryV3.0_sch.pdf | Arduino*Nano* |  |  | 20 | A1 | bidirectional
E |  |  |  |  |  |  |  |  |  |  |  |  |  |  |  |  |  |  |  |  |  |  |  |  |  | MCU_Module | Arduino_Nano_Every | Arduino Nano Every | https://content.arduino.cc/assets/NANOEveryV3.0_sch.pdf | Arduino*Nano* |  |  | 21 | A2 | bidirectional
E |  |  |  |  |  |  |  |  |  |  |  |  |  |  |  |  |  |  |  |  |  |  |  |  |  | MCU_Module | Arduino_Nano_Every | Arduino Nano Every | https://content.arduino.cc/assets/NANOEveryV3.0_sch.pdf | Arduino*Nano* |  |  | 22 | A3 | bidirectional
E |  |  |  |  |  |  |  |  |  |  |  |  |  |  |  |  |  |  |  |  |  |  |  |  |  | MCU_Module | Arduino_Nano_Every | Arduino Nano Every | https://content.arduino.cc/assets/NANOEveryV3.0_sch.pdf | Arduino*Nano* |  |  | 23 | SDA/A4 | bidirectional
E |  |  |  |  |  |  |  |  |  |  |  |  |  |  |  |  |  |  |  |  |  |  |  |  |  | MCU_Module | Arduino_Nano_Every | Arduino Nano Every | https://content.arduino.cc/assets/NANOEveryV3.0_sch.pdf | Arduino*Nano* |  |  | 24 | SCL/A5 | bidirectional
E |  |  |  |  |  |  |  |  |  |  |  |  |  |  |  |  |  |  |  |  |  |  |  |  |  | MCU_Module | Arduino_Nano_Every | Arduino Nano Every | https://content.arduino.cc/assets/NANOEveryV3.0_sch.pdf | Arduino*Nano* |  |  | 25 | A6 | bidirectional
E |  |  |  |  |  |  |  |  |  |  |  |  |  |  |  |  |  |  |  |  |  |  |  |  |  | MCU_Module | Arduino_Nano_Every | Arduino Nano Every | https://content.arduino.cc/assets/NANOEveryV3.0_sch.pdf | Arduino*Nano* |  |  | 26 | A7 | bidirectional
E |  |  |  |  |  |  |  |  |  |  |  |  |  |  |  |  |  |  |  |  |  |  |  |  |  | MCU_Module | Arduino_Nano_Every | Arduino Nano Every | https://content.arduino.cc/assets/NANOEveryV3.0_sch.pdf | Arduino*Nano* |  |  | 27 | +5V | power_out
E |  |  |  |  |  |  |  |  |  |  |  |  |  |  |  |  |  |  |  |  |  |  |  |  |  | MCU_Module | Arduino_Nano_Every | Arduino Nano Every | https://content.arduino.cc/assets/NANOEveryV3.0_sch.pdf | Arduino*Nano* |  |  | 28 | ~{RESET} | input
E |  |  |  |  |  |  |  |  |  |  |  |  |  |  |  |  |  |  |  |  |  |  |  |  |  | MCU_Module | Arduino_Nano_Every | Arduino Nano Every | https://content.arduino.cc/assets/NANOEveryV3.0_sch.pdf | Arduino*Nano* |  |  | 29 | GND | passive
E |  |  |  |  |  |  |  |  |  |  |  |  |  |  |  |  |  |  |  |  |  |  |  |  |  | MCU_Module | Arduino_Nano_Every | Arduino Nano Every | https://content.arduino.cc/assets/NANOEveryV3.0_sch.pdf | Arduino*Nano* |  |  | 30 | VIN | power_in
E |  |  |  |  |  |  |  |  |  |  |  |  |  |  |  |  |  |  |  |  |  |  |  |  |  | Rain Gauge lib | BME280 |  |  |  | U | Reference
E |  |  |  |  |  |  |  |  |  |  |  |  |  |  |  |  |  |  |  |  |  |  |  |  |  | Rain Gauge lib | BME280 |  |  |  | BME280 | Value
E |  |  |  |  |  |  |  |  |  |  |  |  |  |  |  |  |  |  |  |  |  |  |  |  |  | Rain Gauge lib | BME280 |  |  |  |  |  | 1 | VIN | power_in
E |  |  |  |  |  |  |  |  |  |  |  |  |  |  |  |  |  |  |  |  |  |  |  |  |  | Rain Gauge lib | BME280 |  |  |  |  |  | 2 | GND | power_in
E |  |  |  |  |  |  |  |  |  |  |  |  |  |  |  |  |  |  |  |  |  |  |  |  |  | Rain Gauge lib | BME280 |  |  |  |  |  | 3 | SCL | input
E |  |  |  |  |  |  |  |  |  |  |  |  |  |  |  |  |  |  |  |  |  |  |  |  |  | Rain Gauge lib | BME280 |  |  |  |  |  | 4 | SDA | output
E |  |  |  |  |  |  |  |  |  |  |  |  |  |  |  |  |  |  |  |  |  |  |  |  |  | Rain Gauge lib | Electrode |  |  |  | U | Reference
E |  |  |  |  |  |  |  |  |  |  |  |  |  |  |  |  |  |  |  |  |  |  |  |  |  | Rain Gauge lib | Electrode |  |  |  | Electrode | Value
E |  |  |  |  |  |  |  |  |  |  |  |  |  |  |  |  |  |  |  |  |  |  |  |  |  | Rain Gauge lib | Electrode |  |  |  |  |  | 1 | VIN | input
E |  |  |  |  |  |  |  |  |  |  |  |  |  |  |  |  |  |  |  |  |  |  |  |  |  | Rain Gauge lib | Lipo |  |  |  | U | Reference
E |  |  |  |  |  |  |  |  |  |  |  |  |  |  |  |  |  |  |  |  |  |  |  |  |  | Rain Gauge lib | Lipo |  |  |  | Lipo | Value
E |  |  |  |  |  |  |  |  |  |  |  |  |  |  |  |  |  |  |  |  |  |  |  |  |  | Rain Gauge lib | Lipo |  |  |  |  |  | 1 | VIN | power_out
E |  |  |  |  |  |  |  |  |  |  |  |  |  |  |  |  |  |  |  |  |  |  |  |  |  | Rain Gauge lib | Lipo |  |  |  |  |  | 2 | GND | power_in
E |  |  |  |  |  |  |  |  |  |  |  |  |  |  |  |  |  |  |  |  |  |  |  |  |  | Rain Gauge lib | SD_Adapter |  |  |  | U | Reference
E |  |  |  |  |  |  |  |  |  |  |  |  |  |  |  |  |  |  |  |  |  |  |  |  |  | Rain Gauge lib | SD_Adapter |  |  |  | SD_Adapter | Value
E |  |  |  |  |  |  |  |  |  |  |  |  |  |  |  |  |  |  |  |  |  |  |  |  |  | Rain Gauge lib | SD_Adapter |  |  |  |  |  | 1 | 3V3 | power_in
E |  |  |  |  |  |  |  |  |  |  |  |  |  |  |  |  |  |  |  |  |  |  |  |  |  | Rain Gauge lib | SD_Adapter |  |  |  |  |  | 2 | CS | input
E |  |  |  |  |  |  |  |  |  |  |  |  |  |  |  |  |  |  |  |  |  |  |  |  |  | Rain Gauge lib | SD_Adapter |  |  |  |  |  | 3 | MOSI | input
E |  |  |  |  |  |  |  |  |  |  |  |  |  |  |  |  |  |  |  |  |  |  |  |  |  | Rain Gauge lib | SD_Adapter |  |  |  |  |  | 4 | CLK | input
E |  |  |  |  |  |  |  |  |  |  |  |  |  |  |  |  |  |  |  |  |  |  |  |  |  | Rain Gauge lib | SD_Adapter |  |  |  |  |  | 5 | MISO | output
E |  |  |  |  |  |  |  |  |  |  |  |  |  |  |  |  |  |  |  |  |  |  |  |  |  | Rain Gauge lib | SD_Adapter |  |  |  |  |  | 6 | GND | power_in
E |  |  |  |  |  |  |  |  |  |  |  |  |  |  |  |  |  |  |  |  |  |  |  |  |  | Transistor_BJT | PN2222A | 1A Ic, 40V Vce, NPN Transistor, General Purpose Transistor, TO-92 | https://www.onsemi.com/pub/Collateral/PN2222-D.PDF | TO?92* | Q | Reference
E |  |  |  |  |  |  |  |  |  |  |  |  |  |  |  |  |  |  |  |  |  |  |  |  |  | Transistor_BJT | PN2222A | 1A Ic, 40V Vce, NPN Transistor, General Purpose Transistor, TO-92 | https://www.onsemi.com/pub/Collateral/PN2222-D.PDF | TO?92* | PN2222A | Value
E |  |  |  |  |  |  |  |  |  |  |  |  |  |  |  |  |  |  |  |  |  |  |  |  |  | Transistor_BJT | PN2222A | 1A Ic, 40V Vce, NPN Transistor, General Purpose Transistor, TO-92 | https://www.onsemi.com/pub/Collateral/PN2222-D.PDF | TO?92* | Package_TO_SOT_THT:TO-92_Inline | Footprint
E |  |  |  |  |  |  |  |  |  |  |  |  |  |  |  |  |  |  |  |  |  |  |  |  |  | Transistor_BJT | PN2222A | 1A Ic, 40V Vce, NPN Transistor, General Purpose Transistor, TO-92 | https://www.onsemi.com/pub/Collateral/PN2222-D.PDF | TO?92* | https://www.onsemi.com/pub/Collateral/PN2222-D.PDF | Datasheet
E |  |  |  |  |  |  |  |  |  |  |  |  |  |  |  |  |  |  |  |  |  |  |  |  |  | Transistor_BJT | PN2222A | 1A Ic, 40V Vce, NPN Transistor, General Purpose Transistor, TO-92 | https://www.onsemi.com/pub/Collateral/PN2222-D.PDF | TO?92* |  |  | 1 | E | passive
E |  |  |  |  |  |  |  |  |  |  |  |  |  |  |  |  |  |  |  |  |  |  |  |  |  | Transistor_BJT | PN2222A | 1A Ic, 40V Vce, NPN Transistor, General Purpose Transistor, TO-92 | https://www.onsemi.com/pub/Collateral/PN2222-D.PDF | TO?92* |  |  | 2 | B | input
E |  |  |  |  |  |  |  |  |  |  |  |  |  |  |  |  |  |  |  |  |  |  |  |  |  | Transistor_BJT | PN2222A | 1A Ic, 40V Vce, NPN Transistor, General Purpose Transistor, TO-92 | https://www.onsemi.com/pub/Collateral/PN2222-D.PDF | TO?92* |  |  | 3 | C | passive
E |  |  |  |  |  |  |  |  |  |  |  |  |  |  |  |  |  |  |  |  |  |  |  |  |  |  |  |  |  |  |  |  |  |  |  | Device | C:\Program Files\KiCad\6.0\share\kicad\symbols\/Device.kicad_sym
E |  |  |  |  |  |  |  |  |  |  |  |  |  |  |  |  |  |  |  |  |  |  |  |  |  |  |  |  |  |  |  |  |  |  |  | MCU_Module | C:\Program Files\KiCad\6.0\share\kicad\symbols\/MCU_Module.kicad_sym
E |  |  |  |  |  |  |  |  |  |  |  |  |  |  |  |  |  |  |  |  |  |  |  |  |  |  |  |  |  |  |  |  |  |  |  | Rain Gauge lib | C:\Users\cheap\OneDrive\Documents\USC Arduino Lab Projects\Rain Gauge\Rain Gauge/Rain Gauge lib.kicad_sym
E |  |  |  |  |  |  |  |  |  |  |  |  |  |  |  |  |  |  |  |  |  |  |  |  |  |  |  |  |  |  |  |  |  |  |  | Transistor_BJT | C:\Program Files\KiCad\6.0\share\kicad\symbols\/Transistor_BJT.kicad_sym
E |  |  |  |  |  |  |  |  |  |  |  |  |  |  |  |  |  |  |  |  |  |  |  |  |  |  |  |  |  |  |  |  |  |  |  |  |  | 1 | +3V3 | A1 | 17 | 3V3 | power_out
E |  |  |  |  |  |  |  |  |  |  |  |  |  |  |  |  |  |  |  |  |  |  |  |  |  |  |  |  |  |  |  |  |  |  |  |  |  | 1 | +3V3 | U1 | 1 | 3V3 | power_in
E |  |  |  |  |  |  |  |  |  |  |  |  |  |  |  |  |  |  |  |  |  |  |  |  |  |  |  |  |  |  |  |  |  |  |  |  |  | 2 | +5V | A1 | 27 | +5V | power_out
E |  |  |  |  |  |  |  |  |  |  |  |  |  |  |  |  |  |  |  |  |  |  |  |  |  |  |  |  |  |  |  |  |  |  |  |  |  | 2 | +5V | Q1 | 1 | E | passive
E |  |  |  |  |  |  |  |  |  |  |  |  |  |  |  |  |  |  |  |  |  |  |  |  |  |  |  |  |  |  |  |  |  |  |  |  |  | 2 | +5V | U2 | 1 | VIN | power_in
E |  |  |  |  |  |  |  |  |  |  |  |  |  |  |  |  |  |  |  |  |  |  |  |  |  |  |  |  |  |  |  |  |  |  |  |  |  | 2 | +5V | U4 | 1 | VIN | input
E |  |  |  |  |  |  |  |  |  |  |  |  |  |  |  |  |  |  |  |  |  |  |  |  |  |  |  |  |  |  |  |  |  |  |  |  |  | 3 | +BATT | A1 | 30 | VIN | power_in
E |  |  |  |  |  |  |  |  |  |  |  |  |  |  |  |  |  |  |  |  |  |  |  |  |  |  |  |  |  |  |  |  |  |  |  |  |  | 3 | +BATT | U3 | 2 | GND | power_in
E |  |  |  |  |  |  |  |  |  |  |  |  |  |  |  |  |  |  |  |  |  |  |  |  |  |  |  |  |  |  |  |  |  |  |  |  |  | 4 | GND | A1 | 29 | GND | passive
E |  |  |  |  |  |  |  |  |  |  |  |  |  |  |  |  |  |  |  |  |  |  |  |  |  |  |  |  |  |  |  |  |  |  |  |  |  | 4 | GND | A1 | 4 | GND | power_in
E |  |  |  |  |  |  |  |  |  |  |  |  |  |  |  |  |  |  |  |  |  |  |  |  |  |  |  |  |  |  |  |  |  |  |  |  |  | 4 | GND | Q1 | 2 | B | input
E |  |  |  |  |  |  |  |  |  |  |  |  |  |  |  |  |  |  |  |  |  |  |  |  |  |  |  |  |  |  |  |  |  |  |  |  |  | 4 | GND | R2 | 1 |  | passive
E |  |  |  |  |  |  |  |  |  |  |  |  |  |  |  |  |  |  |  |  |  |  |  |  |  |  |  |  |  |  |  |  |  |  |  |  |  | 4 | GND | U1 | 6 | GND | power_in
E |  |  |  |  |  |  |  |  |  |  |  |  |  |  |  |  |  |  |  |  |  |  |  |  |  |  |  |  |  |  |  |  |  |  |  |  |  | 4 | GND | U2 | 2 | GND | power_in
E |  |  |  |  |  |  |  |  |  |  |  |  |  |  |  |  |  |  |  |  |  |  |  |  |  |  |  |  |  |  |  |  |  |  |  |  |  | 4 | GND | U3 | 1 | VIN | power_out
E |  |  |  |  |  |  |  |  |  |  |  |  |  |  |  |  |  |  |  |  |  |  |  |  |  |  |  |  |  |  |  |  |  |  |  |  |  | 5 | Net-(A1-Pad2) | A1 | 2 | RX1 | bidirectional
E |  |  |  |  |  |  |  |  |  |  |  |  |  |  |  |  |  |  |  |  |  |  |  |  |  |  |  |  |  |  |  |  |  |  |  |  |  | 5 | Net-(A1-Pad2) | R1 | 1 |  | passive
E |  |  |  |  |  |  |  |  |  |  |  |  |  |  |  |  |  |  |  |  |  |  |  |  |  |  |  |  |  |  |  |  |  |  |  |  |  | 6 | Net-(A1-Pad5) | A1 | 5 | D2 | bidirectional
E |  |  |  |  |  |  |  |  |  |  |  |  |  |  |  |  |  |  |  |  |  |  |  |  |  |  |  |  |  |  |  |  |  |  |  |  |  | 6 | Net-(A1-Pad5) | R1 | 2 |  | passive
E |  |  |  |  |  |  |  |  |  |  |  |  |  |  |  |  |  |  |  |  |  |  |  |  |  |  |  |  |  |  |  |  |  |  |  |  |  | 7 | Net-(A1-Pad7) | A1 | 7 | D4 | bidirectional
E |  |  |  |  |  |  |  |  |  |  |  |  |  |  |  |  |  |  |  |  |  |  |  |  |  |  |  |  |  |  |  |  |  |  |  |  |  | 7 | Net-(A1-Pad7) | U1 | 2 | CS | input
E |  |  |  |  |  |  |  |  |  |  |  |  |  |  |  |  |  |  |  |  |  |  |  |  |  |  |  |  |  |  |  |  |  |  |  |  |  | 8 | Net-(A1-Pad14) | A1 | 14 | MOSI | bidirectional
E |  |  |  |  |  |  |  |  |  |  |  |  |  |  |  |  |  |  |  |  |  |  |  |  |  |  |  |  |  |  |  |  |  |  |  |  |  | 8 | Net-(A1-Pad14) | U1 | 3 | MOSI | input
E |  |  |  |  |  |  |  |  |  |  |  |  |  |  |  |  |  |  |  |  |  |  |  |  |  |  |  |  |  |  |  |  |  |  |  |  |  | 9 | Net-(A1-Pad15) | A1 | 15 | MISO | bidirectional
E |  |  |  |  |  |  |  |  |  |  |  |  |  |  |  |  |  |  |  |  |  |  |  |  |  |  |  |  |  |  |  |  |  |  |  |  |  | 9 | Net-(A1-Pad15) | U1 | 5 | MISO | output
E |  |  |  |  |  |  |  |  |  |  |  |  |  |  |  |  |  |  |  |  |  |  |  |  |  |  |  |  |  |  |  |  |  |  |  |  |  | 10 | Net-(A1-Pad16) | A1 | 16 | SCK | bidirectional
E |  |  |  |  |  |  |  |  |  |  |  |  |  |  |  |  |  |  |  |  |  |  |  |  |  |  |  |  |  |  |  |  |  |  |  |  |  | 10 | Net-(A1-Pad16) | U1 | 4 | CLK | input
E |  |  |  |  |  |  |  |  |  |  |  |  |  |  |  |  |  |  |  |  |  |  |  |  |  |  |  |  |  |  |  |  |  |  |  |  |  | 11 | Net-(A1-Pad19) | A1 | 19 | A0 | bidirectional
E |  |  |  |  |  |  |  |  |  |  |  |  |  |  |  |  |  |  |  |  |  |  |  |  |  |  |  |  |  |  |  |  |  |  |  |  |  | 11 | Net-(A1-Pad19) | Q1 | 3 | C | passive
E |  |  |  |  |  |  |  |  |  |  |  |  |  |  |  |  |  |  |  |  |  |  |  |  |  |  |  |  |  |  |  |  |  |  |  |  |  | 12 | Net-(A1-Pad23) | A1 | 23 | SDA/A4 | bidirectional
E |  |  |  |  |  |  |  |  |  |  |  |  |  |  |  |  |  |  |  |  |  |  |  |  |  |  |  |  |  |  |  |  |  |  |  |  |  | 12 | Net-(A1-Pad23) | U2 | 4 | SDA | output
E |  |  |  |  |  |  |  |  |  |  |  |  |  |  |  |  |  |  |  |  |  |  |  |  |  |  |  |  |  |  |  |  |  |  |  |  |  | 13 | Net-(A1-Pad24) | A1 | 24 | SCL/A5 | bidirectional
E |  |  |  |  |  |  |  |  |  |  |  |  |  |  |  |  |  |  |  |  |  |  |  |  |  |  |  |  |  |  |  |  |  |  |  |  |  | 13 | Net-(A1-Pad24) | U2 | 3 | SCL | input
E |  |  |  |  |  |  |  |  |  |  |  |  |  |  |  |  |  |  |  |  |  |  |  |  |  |  |  |  |  |  |  |  |  |  |  |  |  | 14 | Net-(R2-Pad2) | R2 | 2 |  | passive
E |  |  |  |  |  |  |  |  |  |  |  |  |  |  |  |  |  |  |  |  |  |  |  |  |  |  |  |  |  |  |  |  |  |  |  |  |  | 14 | Net-(R2-Pad2) | U5 | 1 | VIN | input
E |  |  |  |  |  |  |  |  |  |  |  |  |  |  |  |  |  |  |  |  |  |  |  |  |  |  |  |  |  |  |  |  |  |  |  |  |  | 15 | unconnected-(A1-Pad1) | A1 | 1 | TX1 | bidirectional+no_connect
E |  |  |  |  |  |  |  |  |  |  |  |  |  |  |  |  |  |  |  |  |  |  |  |  |  |  |  |  |  |  |  |  |  |  |  |  |  | 16 | unconnected-(A1-Pad3) | A1 | 3 | ~{RESET} | input+no_connect
E |  |  |  |  |  |  |  |  |  |  |  |  |  |  |  |  |  |  |  |  |  |  |  |  |  |  |  |  |  |  |  |  |  |  |  |  |  | 17 | unconnected-(A1-Pad6) | A1 | 6 | D3 | bidirectional+no_connect
E |  |  |  |  |  |  |  |  |  |  |  |  |  |  |  |  |  |  |  |  |  |  |  |  |  |  |  |  |  |  |  |  |  |  |  |  |  | 18 | unconnected-(A1-Pad8) | A1 | 8 | D5 | bidirectional+no_connect
E |  |  |  |  |  |  |  |  |  |  |  |  |  |  |  |  |  |  |  |  |  |  |  |  |  |  |  |  |  |  |  |  |  |  |  |  |  | 19 | unconnected-(A1-Pad9) | A1 | 9 | D6 | bidirectional+no_connect
E |  |  |  |  |  |  |  |  |  |  |  |  |  |  |  |  |  |  |  |  |  |  |  |  |  |  |  |  |  |  |  |  |  |  |  |  |  | 20 | unconnected-(A1-Pad10) | A1 | 10 | D7 | bidirectional+no_connect
E |  |  |  |  |  |  |  |  |  |  |  |  |  |  |  |  |  |  |  |  |  |  |  |  |  |  |  |  |  |  |  |  |  |  |  |  |  | 21 | unconnected-(A1-Pad11) | A1 | 11 | D8 | bidirectional+no_connect
E |  |  |  |  |  |  |  |  |  |  |  |  |  |  |  |  |  |  |  |  |  |  |  |  |  |  |  |  |  |  |  |  |  |  |  |  |  | 22 | unconnected-(A1-Pad12) | A1 | 12 | D9 | bidirectional+no_connect
E |  |  |  |  |  |  |  |  |  |  |  |  |  |  |  |  |  |  |  |  |  |  |  |  |  |  |  |  |  |  |  |  |  |  |  |  |  | 23 | unconnected-(A1-Pad13) | A1 | 13 | D10 | bidirectional+no_connect
E |  |  |  |  |  |  |  |  |  |  |  |  |  |  |  |  |  |  |  |  |  |  |  |  |  |  |  |  |  |  |  |  |  |  |  |  |  | 24 | unconnected-(A1-Pad18) | A1 | 18 | AREF | input+no_connect
E |  |  |  |  |  |  |  |  |  |  |  |  |  |  |  |  |  |  |  |  |  |  |  |  |  |  |  |  |  |  |  |  |  |  |  |  |  | 25 | unconnected-(A1-Pad20) | A1 | 20 | A1 | bidirectional+no_connect
E |  |  |  |  |  |  |  |  |  |  |  |  |  |  |  |  |  |  |  |  |  |  |  |  |  |  |  |  |  |  |  |  |  |  |  |  |  | 26 | unconnected-(A1-Pad21) | A1 | 21 | A2 | bidirectional+no_connect
E |  |  |  |  |  |  |  |  |  |  |  |  |  |  |  |  |  |  |  |  |  |  |  |  |  |  |  |  |  |  |  |  |  |  |  |  |  | 27 | unconnected-(A1-Pad22) | A1 | 22 | A3 | bidirectional+no_connect
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

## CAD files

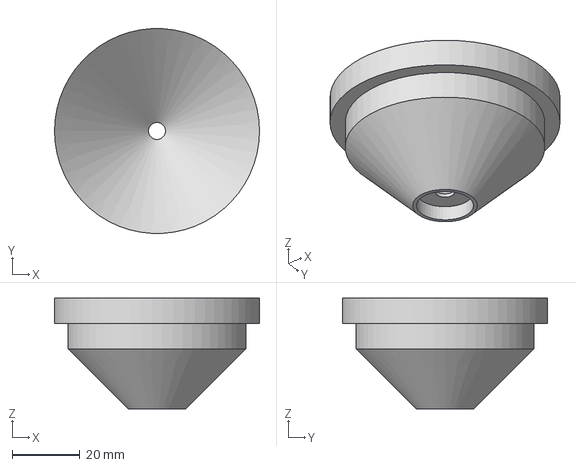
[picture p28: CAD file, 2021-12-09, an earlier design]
Rain_Gauge/V0.2/CAD/PVC_Syphon_reducer_v4 v4.step
60.5 x 60.4 x 32.8 mm

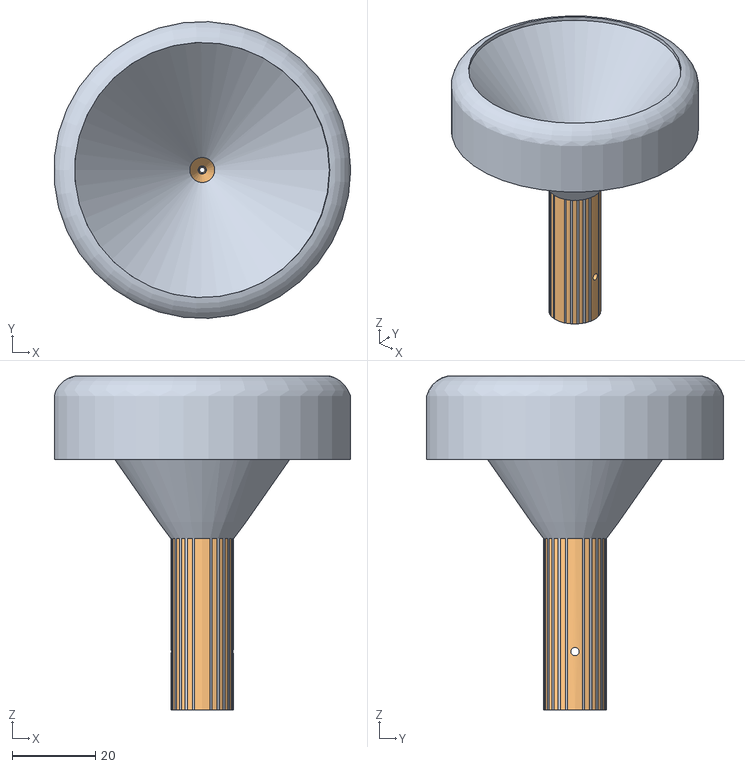
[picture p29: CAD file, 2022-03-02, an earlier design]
Rain_Gauge/V0.3/Fusion/Funnel and Nozzle v7.obj
71.0 x 71.1 x 80.0

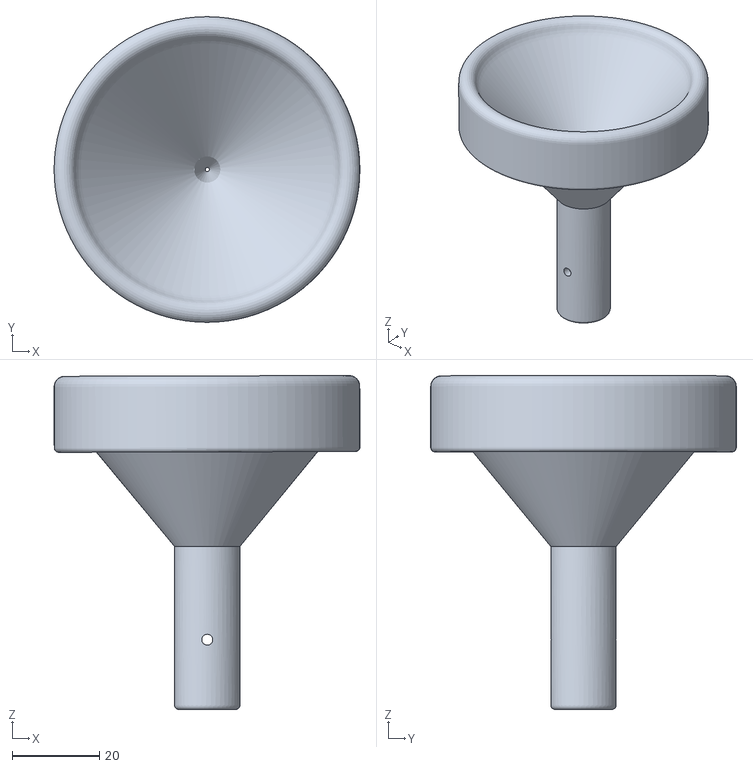
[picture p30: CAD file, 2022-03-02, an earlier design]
Rain_Gauge/V0.5/CAD/print_files/Nozzle and Funnel V2.stl
70.0 x 70.0 x 76.5

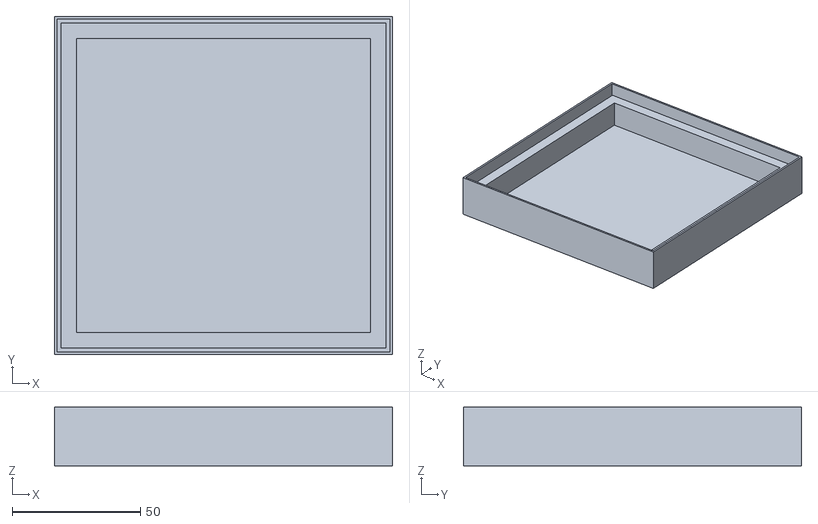
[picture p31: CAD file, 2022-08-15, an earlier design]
Rain_Gauge/V0.6/V0.6.0/CAD/STL Files/Lid v3 .stl
132.0 x 132.0 x 23.0

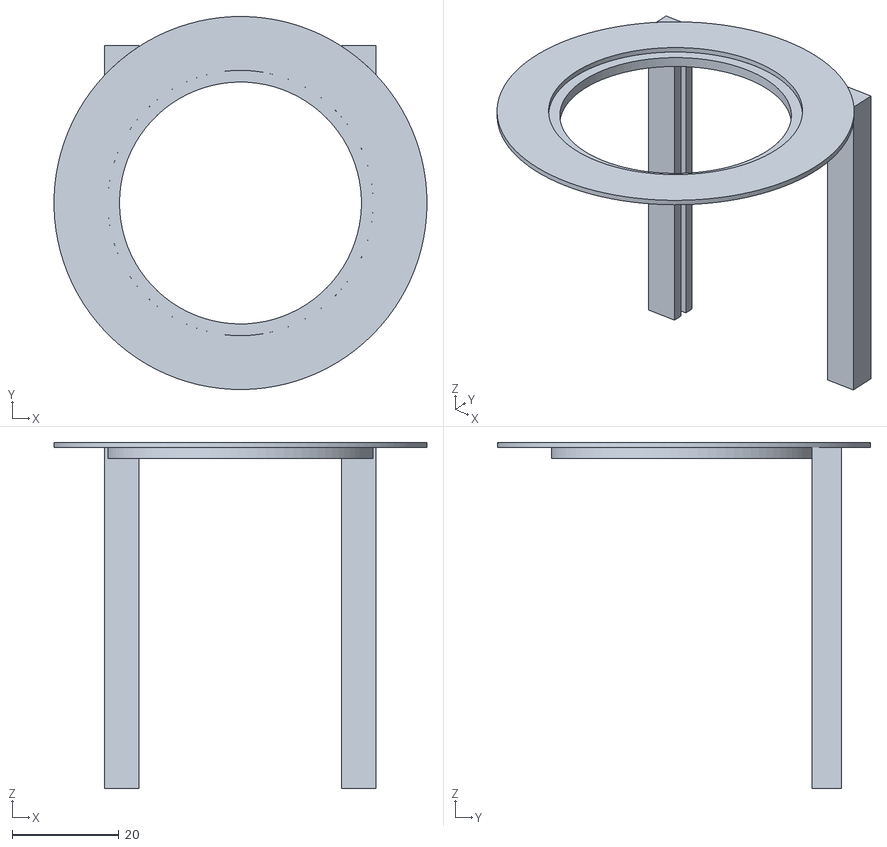
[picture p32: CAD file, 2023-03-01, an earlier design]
Rain_Gauge/V0.6/v0.6.1/CAD/Holder Casing v9.stl
70.0 x 70.0 x 65.0

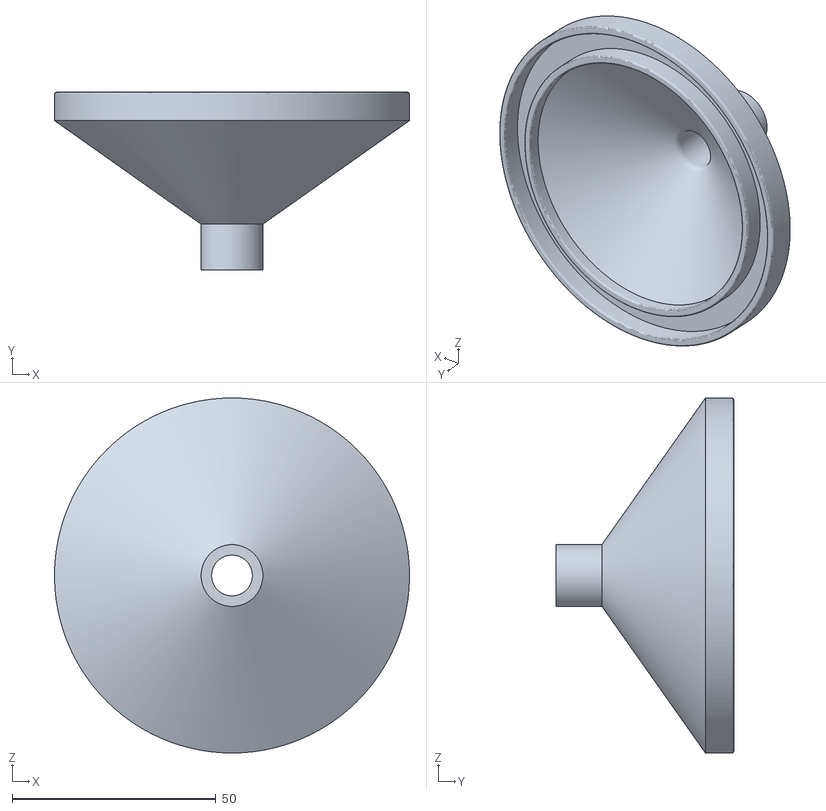
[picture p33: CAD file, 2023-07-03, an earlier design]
Rain_Gauge/V0.6/v0.6.2/CAD Files/Cura Print Files/Drain Funnel v0.6.2.stl
87.1 x 43.6 x 87.1

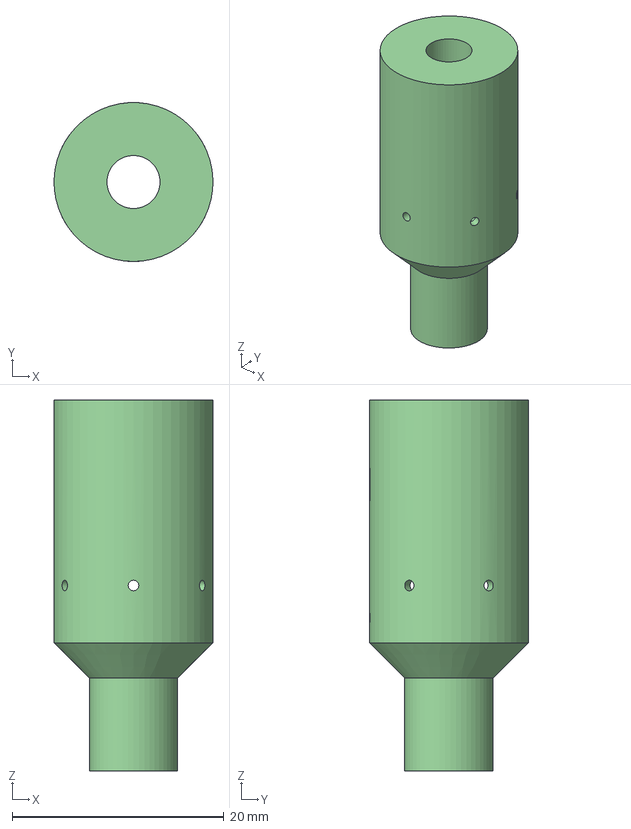
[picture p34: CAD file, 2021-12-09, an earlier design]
Rain_Gauge/V0.2/CAD/PVC_nozzle_and_drain_v1 v3.step
15.0 x 15.0 x 35.0 mm

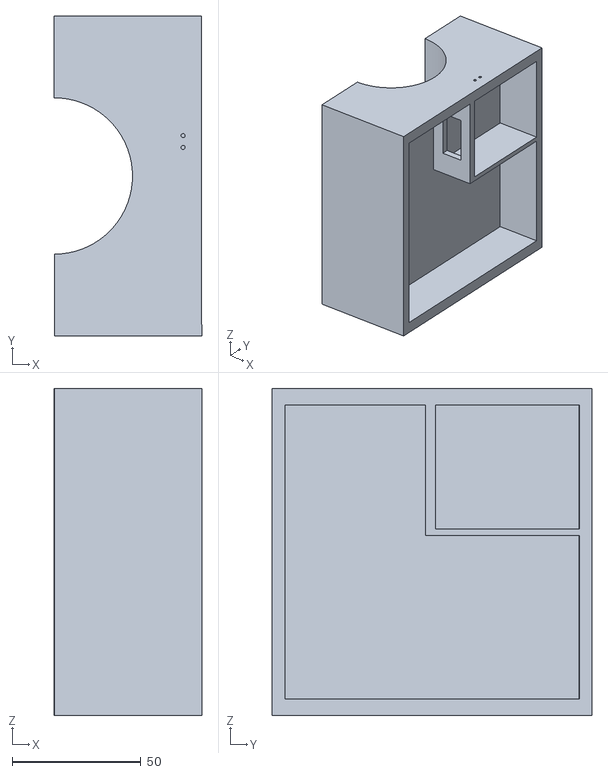
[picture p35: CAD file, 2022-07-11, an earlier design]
Rain_Gauge/V0.6/V0.6.0/CAD/STL Files/Sensor Package v1.stl
57.3 x 124.2 x 127.0

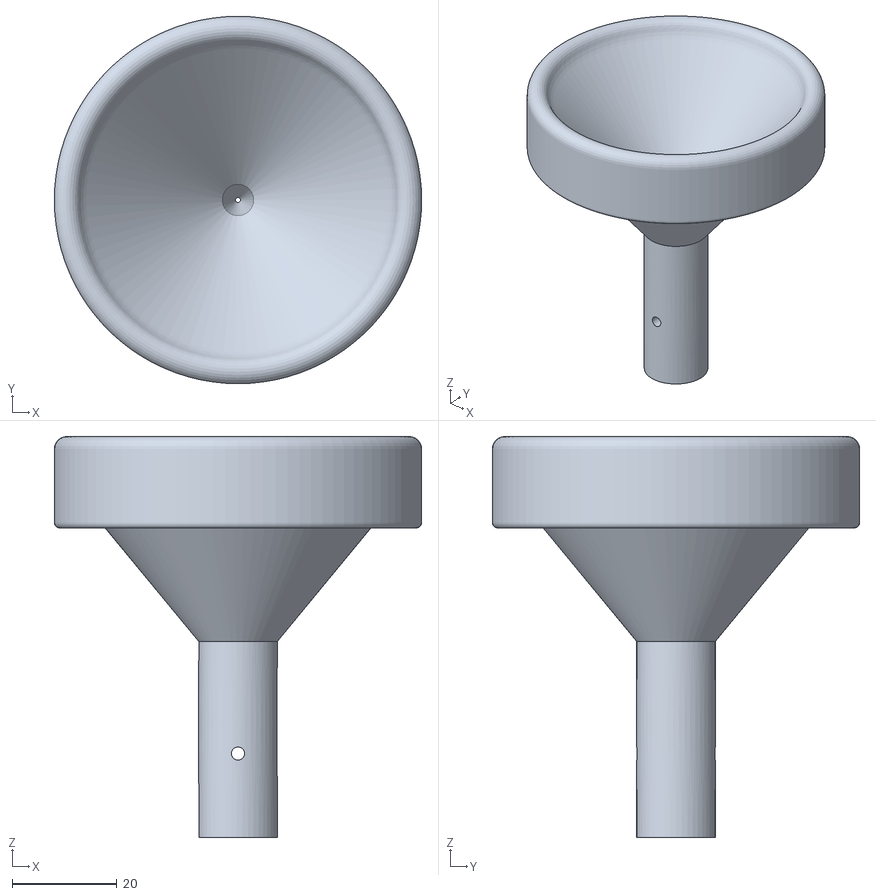
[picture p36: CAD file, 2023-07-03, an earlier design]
Rain_Gauge/V0.6/v0.6.2/CAD Files/Cura Print Files/Electrode Funnel v0.6.2.stl
70.0 x 70.0 x 76.4

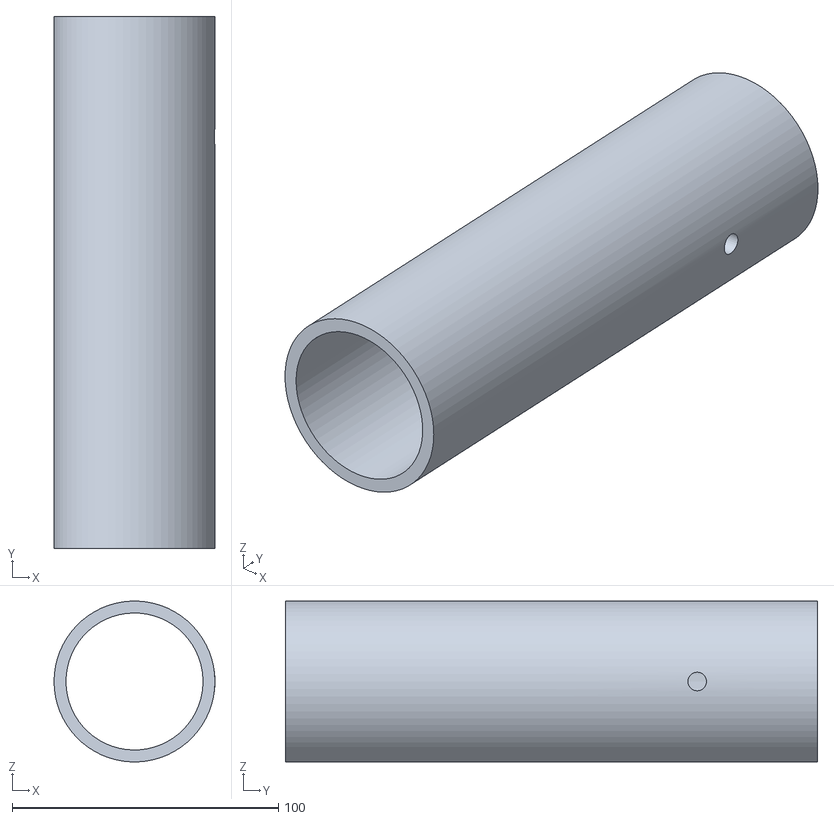
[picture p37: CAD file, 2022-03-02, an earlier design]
Rain_Gauge/V0.5/CAD/print_files/Body.stl
60.5 x 200.0 x 60.4

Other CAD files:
Rain_Gauge/V0.5/CAD/print_files/Nozzle and Funnel V3.stl
Rain_Gauge/V0.2/CAD/PVC_nozzle_and_drain_v1 v2.stl
Rain_Gauge/V0.5/CAD/print_files/Nozzle and Funnel .stl
Rain_Gauge/V0.1/Prototype_v3/Rainfall sensor mid september cut across v2.f3z
Rain_Gauge/V0.1/Prototype_v3/Rainfall sensor mid september v4.f3z
Rain_Gauge/V0.2/CAD/PVC_Syphon_reducer_v4 v4.stl
Rain_Gauge/V0.5/CAD/fusion360_files/Funnel V1.0.f3d
Rain_Gauge/V0.5/CAD/fusion360_files/Nozzle and Funnel V.1 v5.f3d
Rain_Gauge/V0.6/V0.6.0/CAD/F360 Files/Sensor Package v1.f3d
Rain_Gauge/V0.6/v0.6.2/CAD Files/Inventor/Drain Funnel v0.6.2.ipt
Rain_Gauge/V0.6/v0.6.2/CAD Files/Inventor/Electrode Funnel v0.6.2.ipt

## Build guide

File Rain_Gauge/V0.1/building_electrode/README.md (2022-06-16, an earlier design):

# Rain gauge

<p align="center">
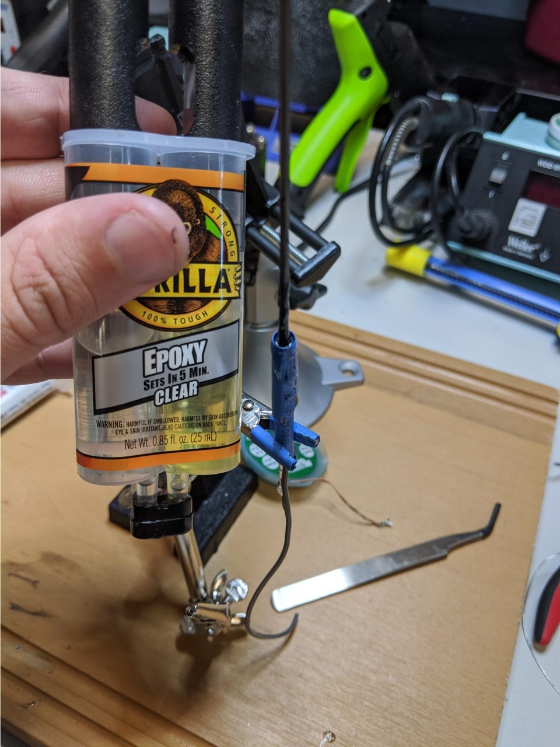
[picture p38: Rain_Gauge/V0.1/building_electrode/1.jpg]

</p>

<p align="center">
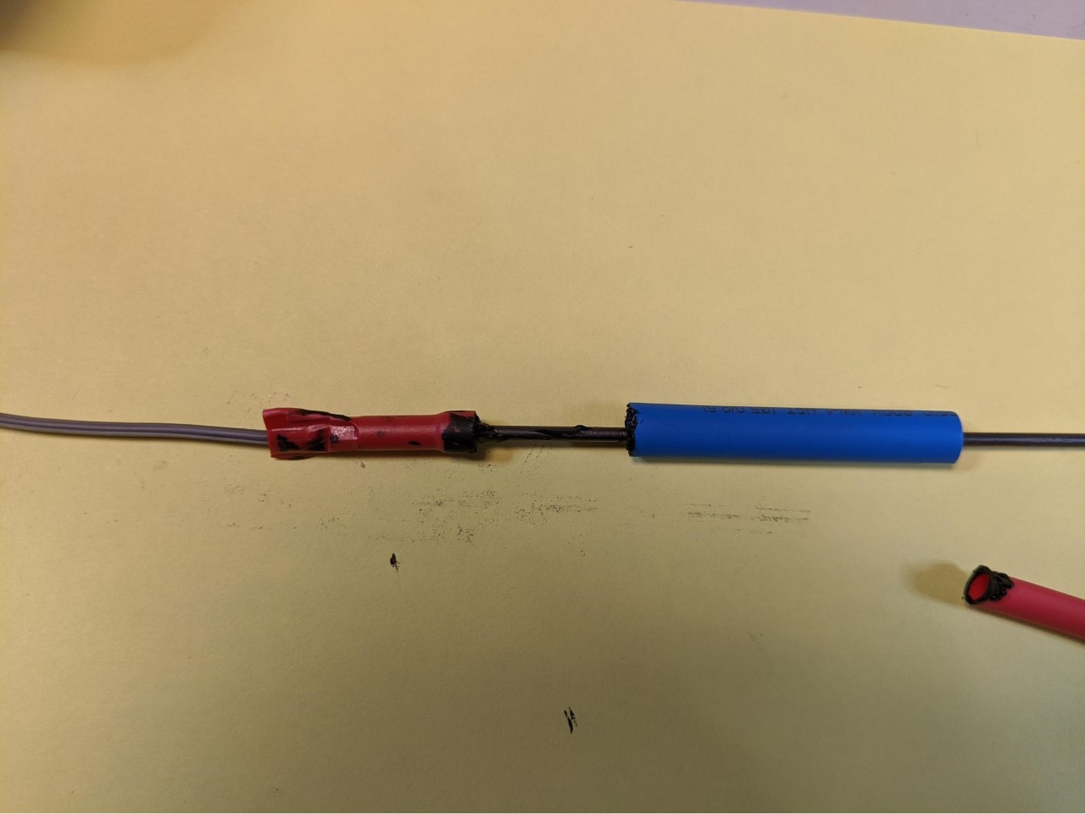
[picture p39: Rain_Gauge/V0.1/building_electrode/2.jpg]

</p>

<p align="center">
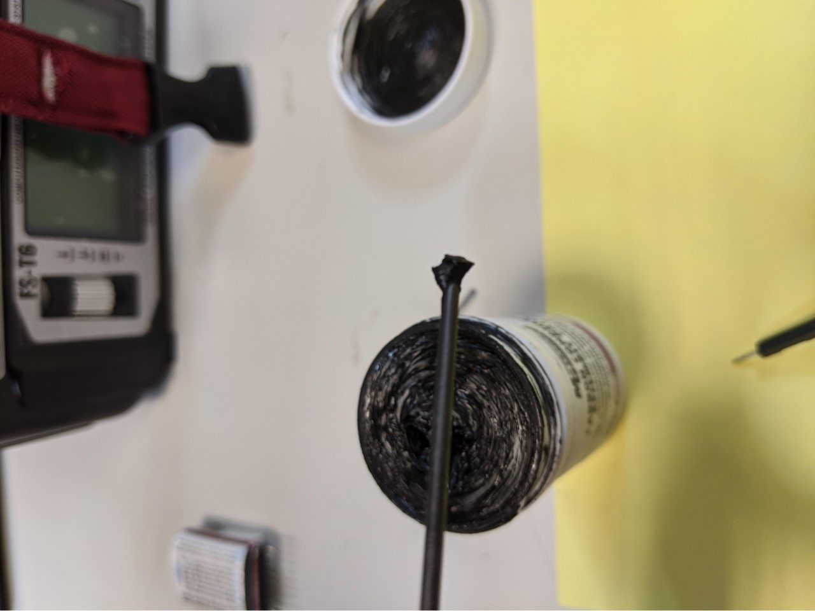
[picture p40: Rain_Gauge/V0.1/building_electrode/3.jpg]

</p>

<p align="center">
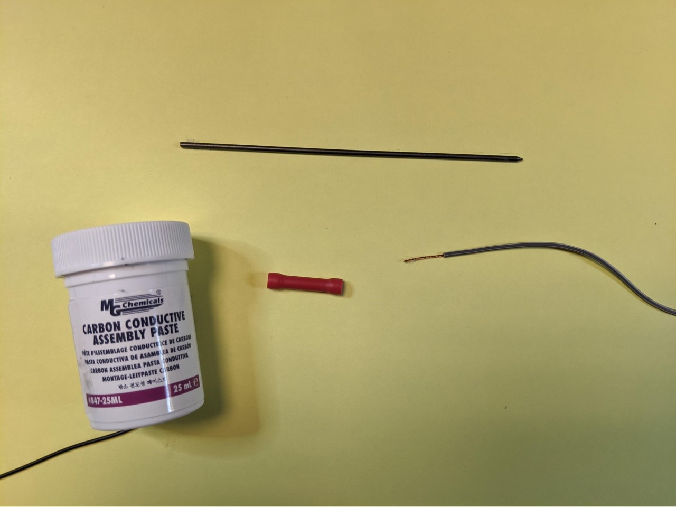
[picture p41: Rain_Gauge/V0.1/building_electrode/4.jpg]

</p>

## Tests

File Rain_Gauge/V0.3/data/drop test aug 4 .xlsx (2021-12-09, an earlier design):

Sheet: using syringe
grams out | drops | drop size g | average drop size | std
0.825 | 21 | 0.03928571429 | 0.04310432051 | 0.003099688473
1.019 | 31 | 0.03287096774
0.826 | 19 | 0.04347368421
0.799 | 17 | 0.047
0.956 | 23 | 0.04156521739
0.752 | 16 | 0.047
0.989 | 23 | 0.043
1.256 | 25 | 0.05024
1.3 | 31 | 0.04193548387
1.13 | 26 | 0.04346153846
1.264 | 34 | 0.03717647059
1.67 | 36 | 0.04638888889
1.555 | 38 | 0.04092105263
1.588 | 35 | 0.04537142857
1.782 | 40 | 0.04455
1.747 | 38 | 0.04597368421
1.759 | 38 | 0.04628947368
2.047 | 47 | 0.04355319149
1.905 | 45 | 0.04233333333
2.006 | 47 | 0.04268085106
2.192 | 46 | 0.04765217391
2.355 | 50 | 0.0471
2.232 | 56 | 0.03985714286
2.663 | 60 | 0.04438333333
2.519 | 52 | 0.04844230769
2.603 | 61 | 0.04267213115
2.765 | 63 | 0.04388888889
2.53 | 53 | 0.04773584906
2.63 | 64 | 0.04109375
2.56 | 60 | 0.04266666667
2.864 | 68 | 0.04211764706
2.832 | 68 | 0.04164705882
2.84 | 67 | 0.0423880597
3.208 | 78 | 0.04112820513
2.603 | 64 | 0.040671875
2.78 | 64 | 0.0434375
2.859 | 64 | 0.044671875
2.823 | 71 | 0.03976056338
2.739 | 66 | 0.0415
2.709 | 63 | 0.043
2.564 | 57 | 0.04498245614
2.554 | 62 | 0.04119354839
2.583 | 63 | 0.041
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

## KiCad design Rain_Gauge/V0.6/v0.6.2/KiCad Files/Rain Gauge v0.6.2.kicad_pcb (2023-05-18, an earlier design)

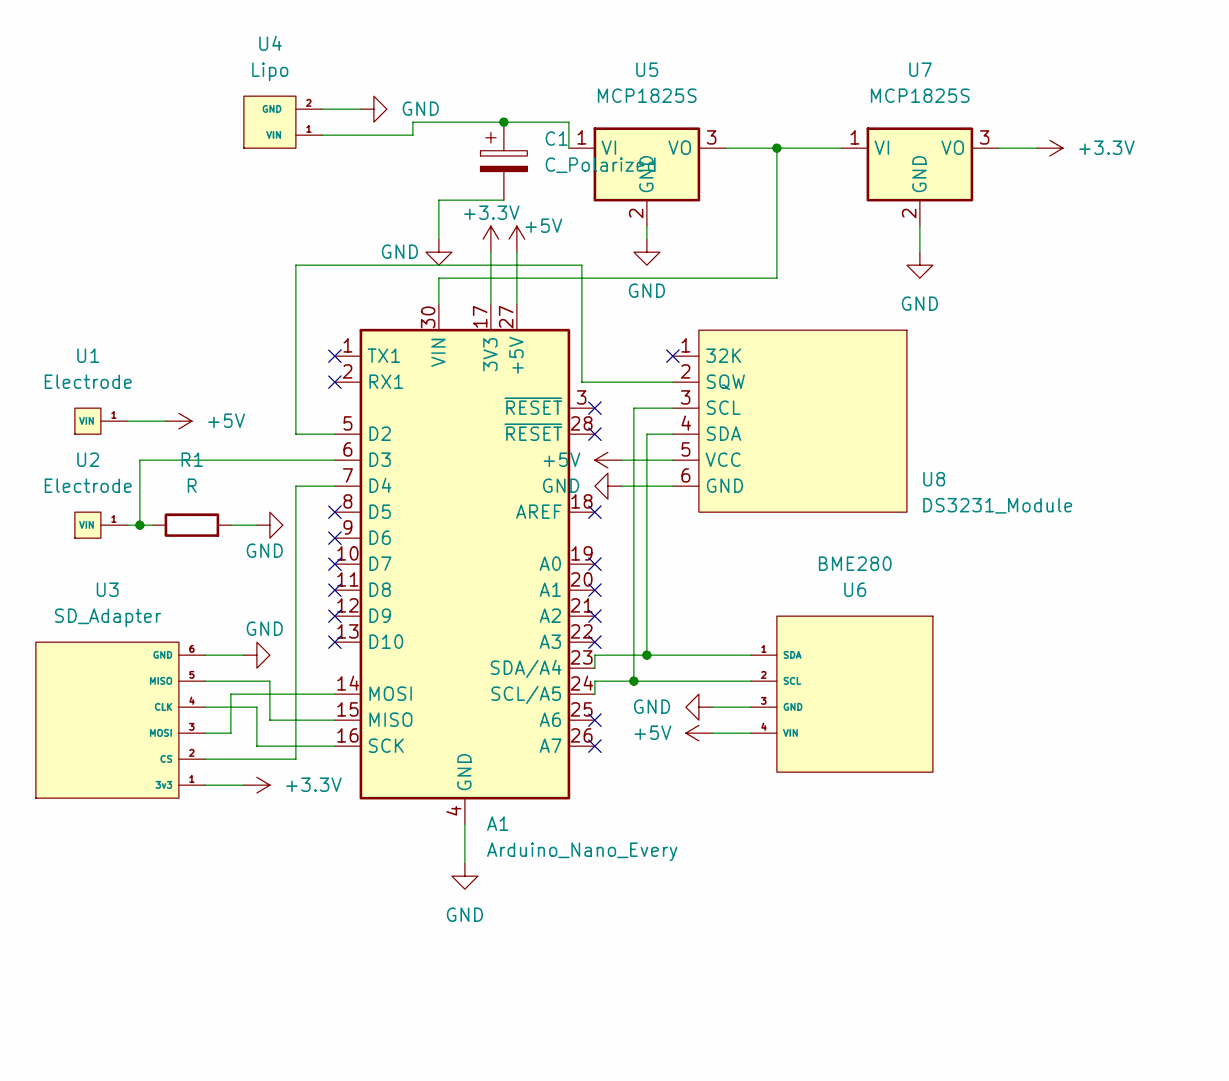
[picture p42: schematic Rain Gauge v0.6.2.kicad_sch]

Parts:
A1: Arduino_Nano_Every; Arduino_Nano
C1: C_Polarized; C_1206_3216Metric
R1: R; R_1206_3216Metric
U1, U2: Electrode
U3: SD_Adapter; 3.3v SD Adapter
U4: Lipo
U5, U7: MCP1825S; SOT230P700X180-4N
U6: BME280
U8: DS3231_Module; 3.3v SD Adapter

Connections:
+3V3: A1.17 (3V3), U3.1 (3v3), U7.3 (VO)
+5V: A1.27 (+5V), U1.1 (VIN), U6.4 (VIN), U8.5 (VCC)
GND: A1.4 (GND), A1.29 (GND), C1.2, R1.2, U3.6 (GND), U4.2 (GND), U5.2 (GND), U6.3 (GND), U7.2 (GND), U8.6 (GND)
unnamed: A1.5 (D2), U8.2 (SQW)
unnamed: A1.6 (D3), R1.1, U2.1 (VIN)
unnamed: A1.7 (D4), U3.2 (CS)
unnamed: A1.14 (MOSI), U3.3 (MOSI)
unnamed: A1.15 (MISO), U3.5 (MISO)
unnamed: A1.16 (SCK), U3.4 (CLK)
unnamed: A1.23 (SDA/A4), U6.1 (SDA), U8.4 (SDA)
unnamed: A1.24 (SCL/A5), U6.2 (SCL), U8.3 (SCL)
unnamed: A1.30 (VIN), U5.3 (VO), U7.1 (VI)
unnamed: C1.1, U4.1 (VIN), U5.1 (VI)

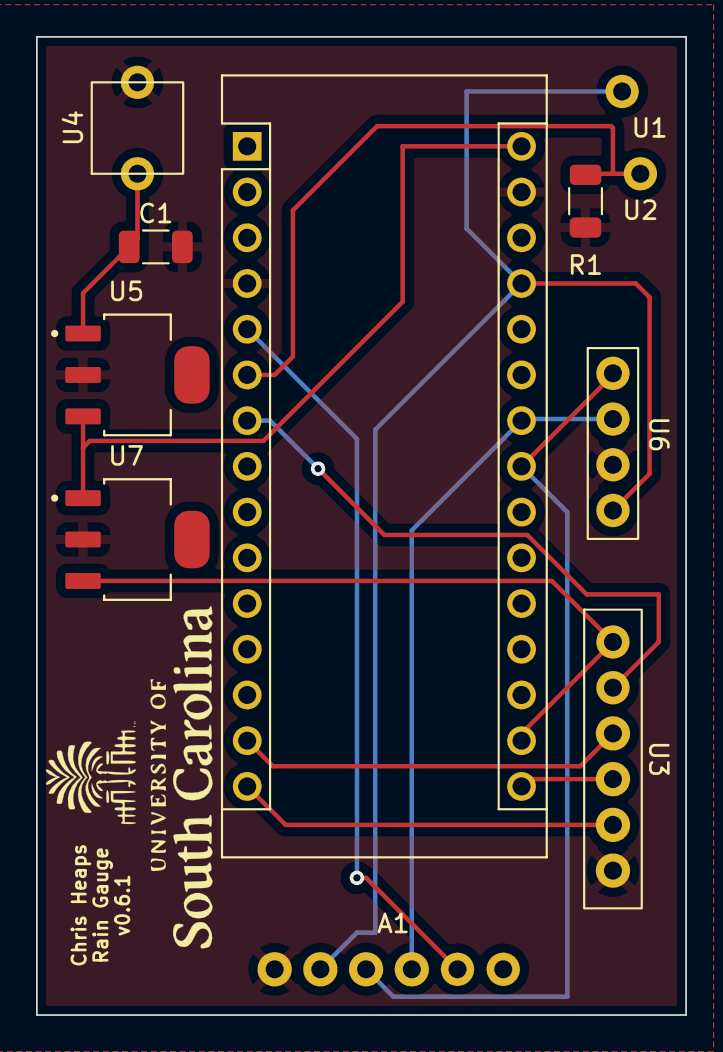
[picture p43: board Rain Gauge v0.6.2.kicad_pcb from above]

Board: 2 copper layers, 36.1 x 54.3 mm, 11 parts (1 on the bottom side), 13 nets.

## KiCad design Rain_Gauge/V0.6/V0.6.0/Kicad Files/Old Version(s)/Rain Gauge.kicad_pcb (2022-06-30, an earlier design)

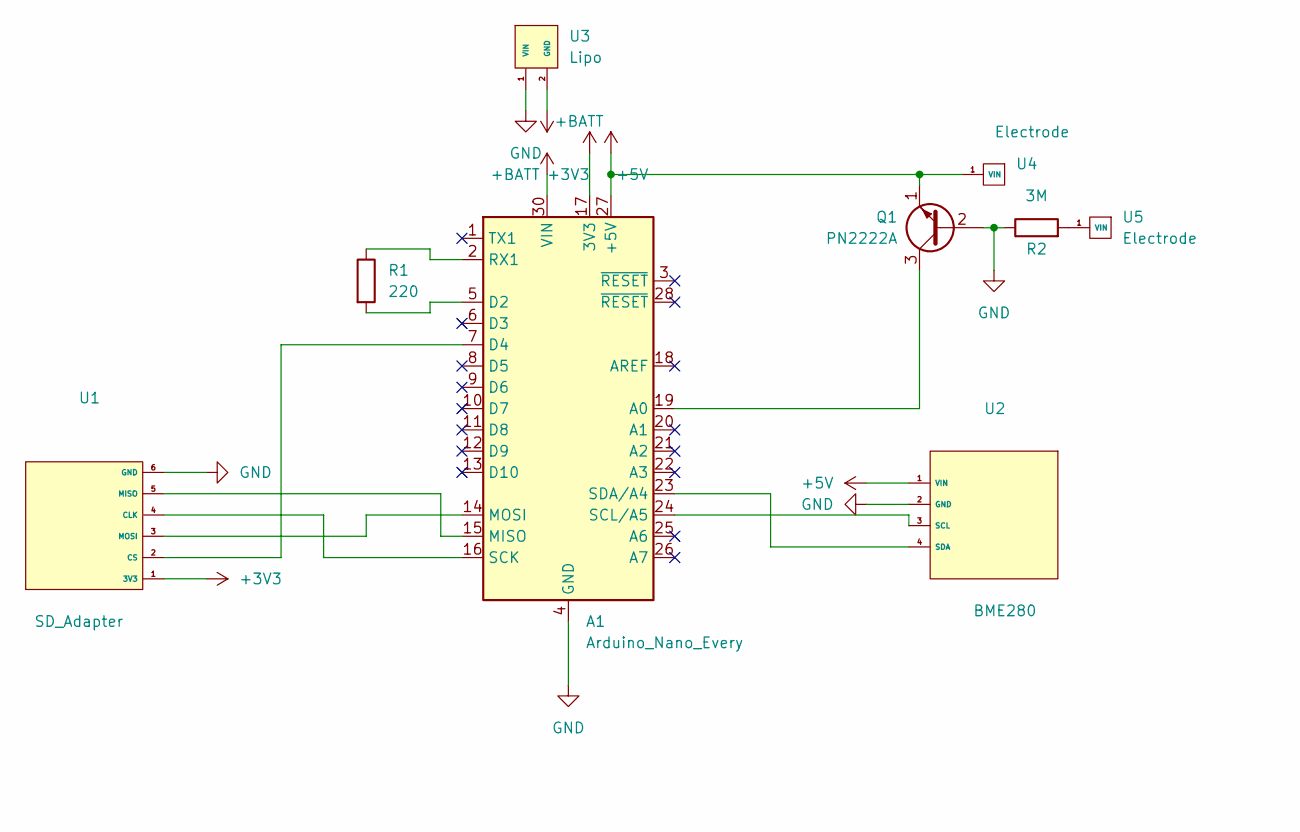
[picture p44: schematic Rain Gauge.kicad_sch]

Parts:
A1: Arduino_Nano_Every; Arduino_Nano
Q1: PN2222A; TO-92_Inline
R1: 220; R_Axial_DIN0207_L6.3mm_D2.5mm_P15.24mm_Horizontal
R2: 3M; R_Axial_DIN0207_L6.3mm_D2.5mm_P15.24mm_Horizontal
U1: SD_Adapter; 3.3v SD Adapter
U2: BME280
U3: Lipo
U4, U5: Electrode

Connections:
+3V3: A1.17 (3V3), U1.1 (3V3)
+5V: A1.27 (+5V), Q1.1 (E), U2.1 (VIN), U4.1 (VIN)
+BATT: A1.30 (VIN), U3.2 (GND)
GND: A1.4 (GND), A1.29 (GND), Q1.2 (B), R2.1, U1.6 (GND), U2.2 (GND), U3.1 (VIN)
unnamed: A1.2 (RX1), R1.1
unnamed: A1.5 (D2), R1.2
unnamed: A1.7 (D4), U1.2 (CS)
unnamed: A1.14 (MOSI), U1.3 (MOSI)
unnamed: A1.15 (MISO), U1.5 (MISO)
unnamed: A1.16 (SCK), U1.4 (CLK)
unnamed: A1.23 (SDA/A4), U2.4 (SDA)
unnamed: A1.24 (SCL/A5), U2.3 (SCL)
unnamed: A1.19 (A0), Q1.3 (C)
unnamed: R2.2, U5.1 (VIN)

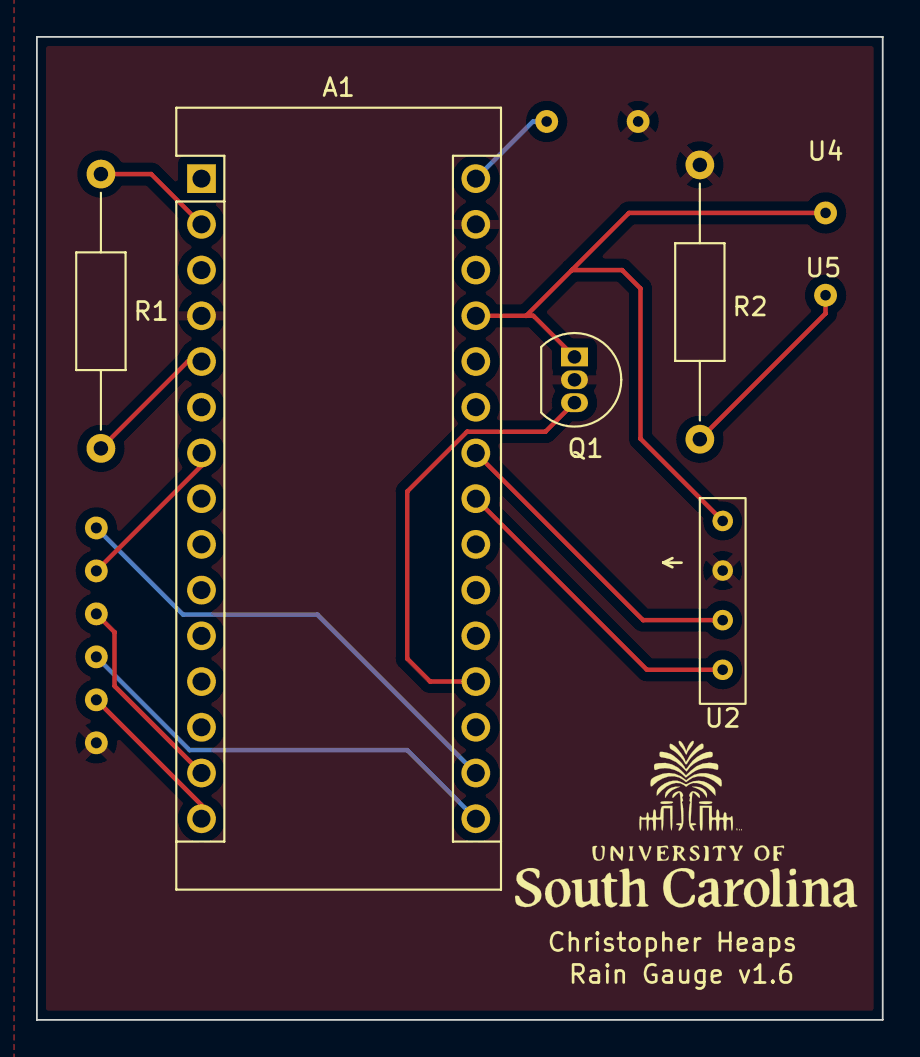
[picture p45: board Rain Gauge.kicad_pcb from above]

Board: 2 copper layers, 47.0 x 54.6 mm, 9 parts (0 on the bottom side), 14 nets.

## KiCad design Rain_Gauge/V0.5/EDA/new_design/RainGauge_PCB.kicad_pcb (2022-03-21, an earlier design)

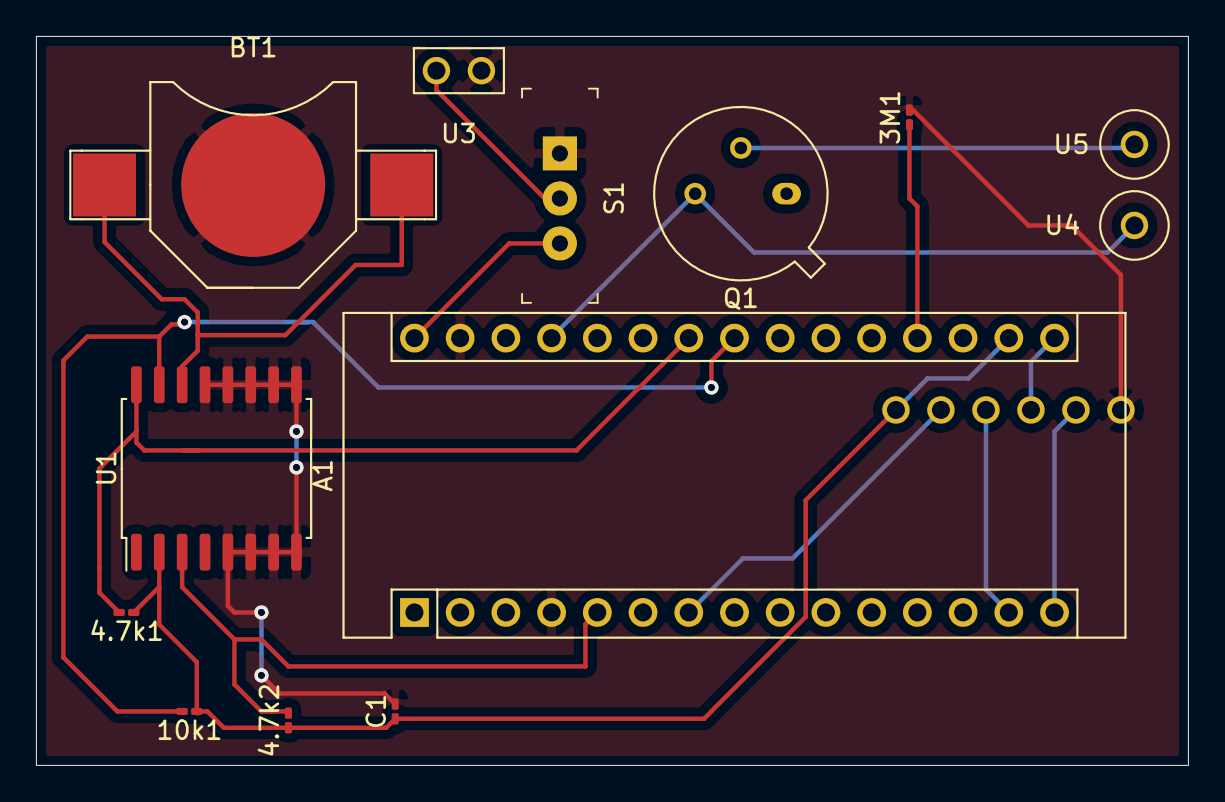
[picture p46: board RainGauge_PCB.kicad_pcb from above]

Board: 2 copper layers, 64.0 x 40.5 mm, 14 parts (1 on the bottom side), 15 nets.

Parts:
3M1, 4.7k1, 4.7k2, 10k1: R; R_0201_0603Metric_Pad0.64x0.40mm_HandSolder
A1: Arduino_Nano_v3.x; Arduino_Nano
BT1: Battery; battery_holder_10mm
C1: C; C_0201_0603Metric_Pad0.64x0.40mm_HandSolder
Q1: 2N2219; TO-39-3
S1: EG1218; Switch_Slide_11.6x4mm_EG1218
U1: DS3231M; SOIC-16W_7.5x10.3mm_P1.27mm
U2: SD_Card; SD_card
U3: Battery_Leads; battery_leads
U4, U5: Electrode_TH; electrode

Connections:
GND: 3M1.2, A1.4, A1.29, BT1.2, C1.2, S1.1, U1.5, U1.6, U1.7, U1.8, U1.9, U1.10, U1.11, U1.12, U1.13, U2.1, U3.2
unnamed: 3M1.1, A1.19
unnamed: 4.7k1.2, A1.24, U1.16
unnamed: 4.7k2.2, A1.5, U1.3
unnamed: 4.7k1.1, 4.7k2.1, 10k1.1, A1.17, C1.1, U1.2, U2.6
unnamed: 10k1.2, A1.23, U1.15
unnamed: A1.7, U2.5
unnamed: A1.14, U2.4
unnamed: A1.15, U2.2
unnamed: A1.16, U2.3
unnamed: A1.27, Q1.3, U4.1
unnamed: A1.30, S1.3
unnamed: BT1.1, U1.14
unnamed: Q1.2, U5.1
unnamed: S1.2, U3.1

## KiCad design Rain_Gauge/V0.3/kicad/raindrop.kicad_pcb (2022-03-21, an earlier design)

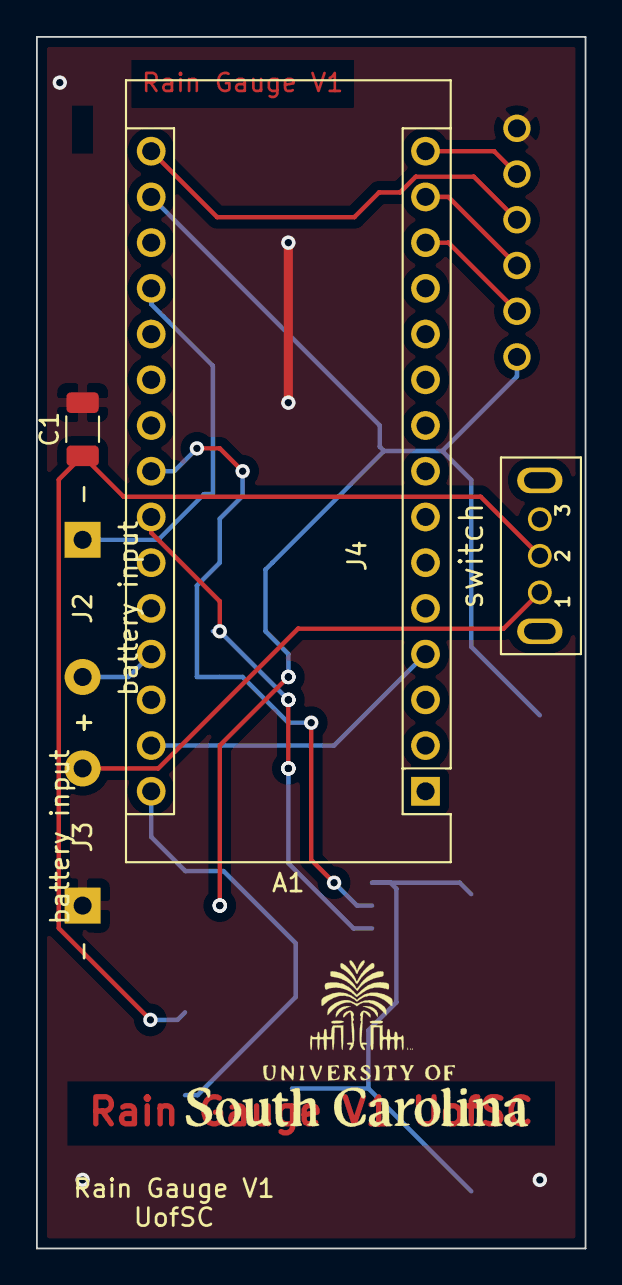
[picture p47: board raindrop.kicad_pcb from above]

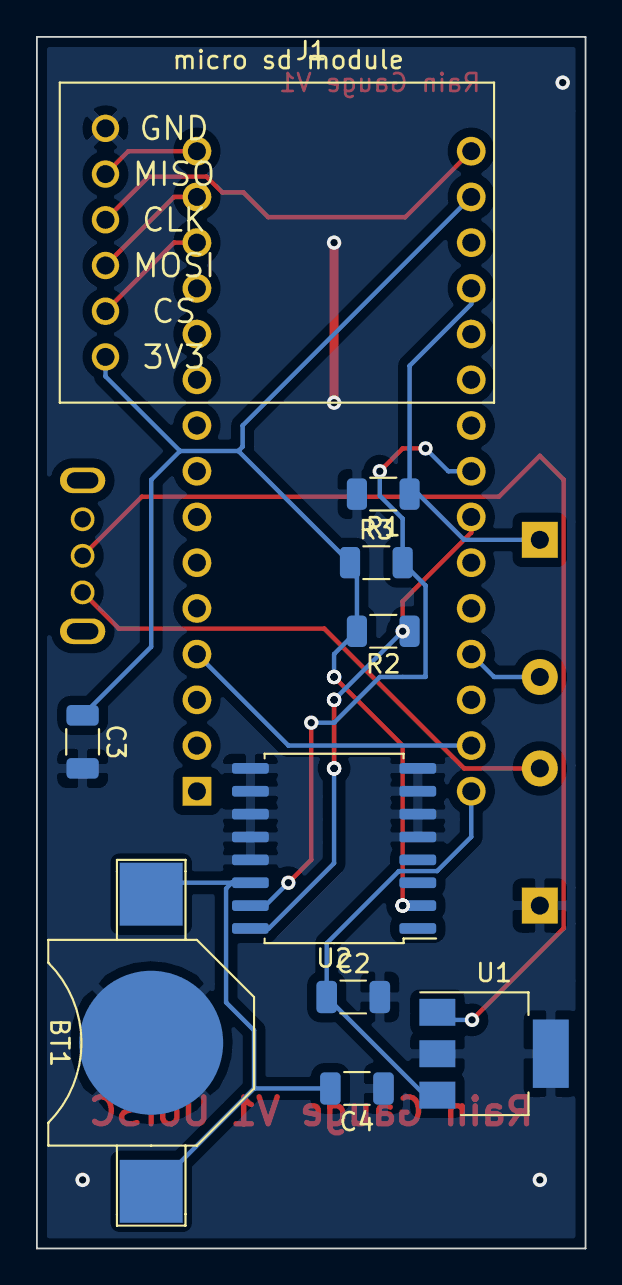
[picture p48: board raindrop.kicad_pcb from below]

Board: 2 copper layers, 30.5 x 67.3 mm, 15 parts (10 on the bottom side), 15 nets.

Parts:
A1: Arduino_Nano_v3.x; Arduino_Nano
BT1: Battery_Cell; battery_holder_10mm
C1, C2, C3, C4: C; C_1206_3216Metric
J1: Saif_micro_sd; SD_Module
J2: Screw_Terminal_01x02; Battery_Input
J3: Conn_01x02_Female; Battery_Input
J4: switch; grounded_switch
R1, R2, R3: R; R_1206_3216Metric
U1: L7805; SOT-223-3_TabPin2
U2: DS3231M; SOIC-16W_7.5x10.3mm_P1.27mm

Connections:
Earth: BT1.2, C1.2, C2.2, C3.2, C4.1, J1.6, J3.2, R1.2, U1.2, U2.5, U2.6, U2.7, U2.8, U2.9, U2.10, U2.11, U2.12, U2.13
GND: A1.4, A1.29
unnamed: A1.13, J1.2
unnamed: A1.14, J1.3
unnamed: A1.15, J1.5
unnamed: A1.16, J1.4
unnamed: A1.17, C3.1, J1.1, R2.2, R3.1, U2.2
unnamed: A1.19, J2.2, R1.1
unnamed: A1.23, R3.2, U2.15
unnamed: A1.24, R2.1, U2.16
unnamed: A1.27, J2.1
unnamed: A1.30, C2.1, U1.3
unnamed: BT1.1, C4.2, U2.14
unnamed: C1.1, J4.2, U1.1
unnamed: J3.1, J4.1

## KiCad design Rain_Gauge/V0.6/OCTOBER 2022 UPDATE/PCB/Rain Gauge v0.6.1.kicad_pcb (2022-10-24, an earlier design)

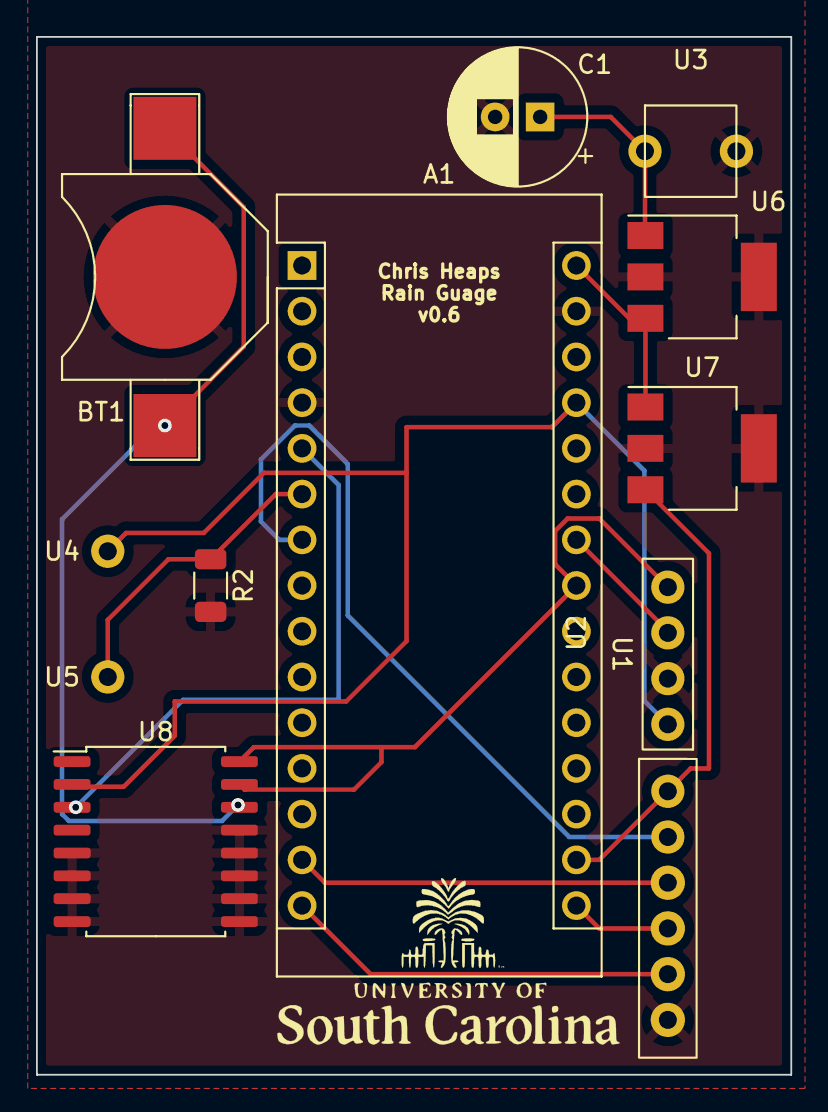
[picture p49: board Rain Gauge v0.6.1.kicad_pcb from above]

Board: 2 copper layers, 41.9 x 57.7 mm, 12 parts (0 on the bottom side), 14 nets.

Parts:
A1: Arduino_Nano_Every; Arduino_Nano
BT1: Battery_Cell; battery_holder_10mm
C1: C_Polarized; CP_Radial_D7.5mm_P2.50mm
R2: 3M; R_1206_3216Metric
U1: SD_Adapter; 3.3v SD Adapter
U2: BME280
U3: Lipo
U4, U5: Electrode
U6: LM2937xMP; SOT-223-3_TabPin2
U7: MCP1825S; SOT-223-3_TabPin2
U8: DS3231M; SOIC-16W_7.5x10.3mm_P1.27mm

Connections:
+3V3: A1.17 (3V3), U1.1 (3V3), U7.3 (VO)
+5V: A1.27 (+5V), U2.1 (VIN), U4.1 (VIN), U8.2 (VCC)
GND: A1.4 (GND), A1.29 (GND), BT1.2 (-), C1.2, R2.2, U1.6 (GND), U2.2 (GND), U3.2 (GND), U6.2 (GND), U7.2 (GND), U8.5 (GND), U8.6 (GND), U8.7 (GND), U8.8 (GND), U8.9 (GND), U8.10 (GND), U8.11 (GND), U8.12 (GND), U8.13 (GND)
unnamed: A1.5 (D2), U8.3 (~INT/SQW)
unnamed: A1.6 (D3), R2.1, U5.1 (VIN)
unnamed: A1.7 (D4), U1.2 (CS)
unnamed: A1.14 (MOSI), U1.3 (MOSI)
unnamed: A1.15 (MISO), U1.5 (MISO)
unnamed: A1.16 (SCK), U1.4 (CLK)
unnamed: A1.23 (SDA/A4), U2.4 (SDA), U8.15 (SDA), U8.16 (SCL)
unnamed: A1.24 (SCL/A5), U2.3 (SCL)
unnamed: A1.30 (VIN), U6.3 (VO), U7.1 (VI)
unnamed: BT1.1 (+), U8.14 (VBAT)
unnamed: C1.1, U3.1 (VIN), U6.1 (VI)

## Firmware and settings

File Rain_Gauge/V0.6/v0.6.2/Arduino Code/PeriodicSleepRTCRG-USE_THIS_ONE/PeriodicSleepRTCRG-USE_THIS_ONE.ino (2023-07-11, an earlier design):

#include <RTClib.h>     // DS3231 library
#include <avr/sleep.h>  // AVR library for controlling the sleep modes
#include <Adafruit_BME280.h>
#include <SPI.h>
#include <Wire.h>
#include <SD.h>

#define SEALEVELPRESSURE_HPA (1013.25)
#define chipSelect 4

//When activating the Arduino for testing, make sure you turn on the auxilary power before disconnecting from computer, makes sure the RTC keeps accurate time

File myFile;

Adafruit_BME280 bme;

const int alarmPin = 2; // The number of the pin for monitoring alarm status on DS3231

unsigned long dropcount = 1;    //variable that we store raindrop counts in

const int rain = 1;    //% humidity that wakes the system (52-54 %)

RTC_DS3231 rtc;

int sensor = digitalRead(3);

void setup () {
  Serial.begin(115200); // Start serial port for monitoring
  
  while (!Serial) {
    ; // wait for serial port to connect. Needed for native USB port only
  }

  if (!bme.begin(0x76))   {
    Serial.println("Could not find a valid BME280 sensor,check wiring");
    while (1);
  }



  pinMode(alarmPin, INPUT_PULLUP); // Set alarm pin as pullup

  if (! rtc.begin()) {
    Serial.println("Couldn't find RTC");
    Serial.flush();
    abort();
  }

    rtc.adjust(DateTime(F(__DATE__) , F(__TIME__)));

  // If required set time
  //rtc.adjust(DateTime(F(__DATE__), F(__TIME__))); // To compiled time
  //rtc.adjust(DateTime(2020, 7, 3, 20, 0, 0)); // Or explicitly, e.g. July 3, 2020 at 8pm

  // Disable and clear both alarms
  rtc.disableAlarm(1);
  rtc.disableAlarm(2);
  rtc.clearAlarm(1);
  rtc.clearAlarm(2);

  rtc.writeSqwPinMode(DS3231_OFF); // Place SQW pin into alarm interrupt mode

  Serial.print("Initializing SD card...");

  // see if the card is present and can be initialized:
  if (!SD.begin(chipSelect)) {
    Serial.println("Card failed, or not present");
    // don't do anything more:
    while (1);
  }
  Serial.println("card initialized.");
  delay(1000);
  Serial.println("Starting");
}

void loop () {

  if (bme.readHumidity() > rain)  {
    
    if (digitalRead(3) > 0) {



      //
      File myFile = SD.open("u6.csv", FILE_WRITE);
      if (myFile)  {    //Keeps Arduino awake and logs drop count data
        DateTime now = rtc.now();
        Serial.println();
        Serial.print(now.hour(), DEC);
        Serial.print(":");
        Serial.print(now.minute() , DEC);
        Serial.print(":");
        Serial.print(now.second(), DEC);
        Serial.print("\t");
        Serial.print(bme.readHumidity());
        Serial.print("\t");
        Serial.print("%");
        Serial.print("\t");
        Serial.print(digitalRead(3));
        Serial.print("\t");
        Serial.print(dropcount);

        
       //myFile.print(now.month(), DEC);
      // myFile.print("/");
      //  myFile.print(now.day(), DEC);
        myFile.print(now.hour(), DEC);
       myFile.print(":");
        myFile.print(now.minute(), DEC);
        myFile.print(":");
        myFile.print(now.second(), DEC);
        myFile.print(",");
        myFile.print(bme.readHumidity());
        myFile.print("%");
        myFile.print(",");
        myFile.print(dropcount);
        myFile.println();
        myFile.close();
        delay(500);           //interval on which the gauge counts raindrops, can be tweaked to create smoother data 
        dropcount = dropcount + 1;


      }

      else  {
        Serial.println("SD is FUBAR");
        delay(1000);
      }

    }
    else {
      Serial.println("No rain connecting electrodes");
      delay(1000);
    }





  }

  else {                                                      //This will make the Arduino sleep if humidity is too low
    delay(2000);  // Wait 10 seconds before going to sleep

    // Get current time and set alarm to a time to wake
    DateTime now = rtc.now();  // Get current time
    rtc.setAlarm1(now + TimeSpan(0, 0, 0, 05), DS3231_A1_Second); // In 10 seconds
    //rtc.setAlarm1(DateTime(2020, 6, 25, 15, 0, 0), DS3231_A1_Hour); // Or can be set explicity

    enterSleep();  // Go to sleep
  }
}

void enterSleep() {
  sleep_enable();                       // Enabling sleep mode
  set_sleep_mode(SLEEP_MODE_PWR_DOWN);  // Setting the sleep mode, in this case full sleep

  noInterrupts();                       // Disable interrupts
  attachInterrupt(digitalPinToInterrupt(alarmPin), alarm_ISR, LOW);

  Serial.println("Going to sleep!");    // Print message to serial monitor
  Serial.flush();                       // Ensure all characters are sent to the serial monitor

  interrupts();                         // Allow interrupts again
  sleep_cpu();                          // Enter sleep mode

  /* The program will continue from here when it wakes */

  // Disable and clear alarm
  rtc.disableAlarm(1);
  rtc.clearAlarm(1);

  Serial.println("No rain");          // Print message to show we're back
}


void alarm_ISR() {
  // This runs when SQW pin is low. It will wake up the µController

  sleep_disable(); // Disable sleep mode
  detachInterrupt(digitalPinToInterrupt(alarmPin)); // Detach the interrupt to stop it firing
}

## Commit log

2021-12-09 initial comit
    [4_20_S0.CSV, 4_20_S1.CSV, 4_20_S2.CSV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]
2022-02-02 created new version
    [Funnel and Nozzle v7.obj, component list.xlsx, drop test aug 4 .xlsx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]
2022-02-02 cleaning up file setup
    [Funnel and Nozzle v7.obj, component list.xlsx, drop test aug 4 .xlsx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]
2022-02-18 these are my changes
    [RainGauge_PCB.kicad_pcb, RainGauge_PCB.sch]
2022-02-18 clean up files
    [Funnel and Nozzle v7.obj, RainGauge_PCB.kicad_pcb, RainGauge_PCB.sch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]
2022-02-18 cleaned up Ryan's files
    [Funnel and Nozzle v7.obj, RainGauge_PCB.kicad_pcb, RainGauge_PCB.sch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]
2022-02-18 add ARTS-lab footprints and symbols
2022-02-21 Adding Ava's stuff
    [MicroSD.kicad_pcb, MicroSD.sch, New_schematic.kicad_pcb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]
2022-02-24 Reorganize and new PCB
    [RainGauge_PCB.kicad_pcb]
2022-03-02 KiCad Stuff
    [Body.stl, Funnel V1.0.f3d, Funnel and Nozzle v7.obj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]
2022-06-10 Added a condition that only lets Arduino work at a certain humidity level-saves power
    This code takes TDS readings at a certain humidity level from a BME280 sensor and saves to a microSD card in Excel format. The Arduino is asleep otherwise to help save power and not take unnecessary 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
2022-06-13 Cap for PVC
    Planning to make the gauge in a pvc pipe with a funnel leading into it- this is just a quick version for prototyping.
    [PVC End Cap v1.f3d]
2022-06-30 Chris' Work
    [Rain Gauge BOM.xlsx, Rain Gauge.kicad_pcb, Rain Gauge.kicad_sch]
2022-07-11 Chris' work
    Sensor housing for rain gauge- has space for PCB and battery.
    [PVC End Cap v1.f3d, Sensor Package v1.f3d, Sensor Package v1.stl]
2022-07-13 Renamed folder versions
    [4_20_S0.CSV, 4_20_S1.CSV, 4_20_S2.CSV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]
2022-09-08 9/8/2022 Update-Chris H.
    [Lid v3 .stl, Rain Gauge BOM.xlsx, Rain Gauge.kicad_pcb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]
2022-10-24 October 2022 Update-Chris H.
    [Rain Gauge v0.6.1.kicad_pcb]
2023-03-01 Adding v0.6.1- latest work
    [Holder Casing v9.stl]
2023-05-18 Adding KiCad and Program files
    Adding files for a redesigned PCB that will be used for a working prototype for now- will add 3d print & CAD files soon
2023-05-18 Kicad Files
    [Rain Gauge v0.6.2.kicad_pcb, Rain Gauge v0.6.2.kicad_sch]
2023-07-03 Version number updates
    [Drain Funnel v0.6.2.ipt, Drain Funnel v0.6.2.stl, Electrode Funnel v0.6.2.ipt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]
2023-07-11 Update to Arduino code
